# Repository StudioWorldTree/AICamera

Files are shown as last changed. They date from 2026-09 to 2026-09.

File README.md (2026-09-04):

# AICamera

Hardware home for the All Systems Go AI camera. Thor body, HEVC record path, Cooke /i lens metadata, hybrid CSI / PoE plant.

**Notebook:** [studioworldtree.github.io/AICamera](https://studioworldtree.github.io/AICamera/)

Product ground (pipeline, modes, models, vision) lives in `web3d-space`. This repo is the camera body: carriers, sensors, interconnect, enclosures, datasheets.

## Site

SvelteKit static + [mdsvex](https://mdsvex.pngwn.io). Markdown in `docs/`, `openspec/`, and `AGENTS.md` is compiled into `/docs/…`.

```sh
npm install
npm run dev
npm run build   # BASE_PATH=/AICamera in CI
```

### CMS

The notebook is still SvelteKit static + mdsvex. Editors use [Sveltia CMS](https://github.com/sveltia/sveltia-cms) at `/admin/` in local `npm run dev`, and at https://studioworldtree.github.io/AICamera/admin/ on Pages. Sign in with a GitHub personal access token that can write this repo (classic `repo`, or fine-grained `contents:write`). Token auth only; no OAuth worker in this pass. Commits go to `main` and Pages rebuilds. Do not put locked decisions, openspec packets, or CAD/GLB in the CMS.

## Kit (locked)

- Lab brick: Jetson AGX Thor Developer Kit = T5000 module
- Production ceiling: T4000 SOM unless satellite count forces T5000
- Bring-up: 1 body + 2 satellites at 4K30
- Record: HEVC. Lens: Cooke /i JSONL sidecar

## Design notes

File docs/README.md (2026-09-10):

---
title: "Hardware docs"
kicker: "Index"
group: "meta"
summary: "This repo is the camera body. Product ground (vision, pipeline, modes, models) lives in web3d-space. Do not fork it."
---

# AICamera hardware docs

This repo is the **camera body**: Thor carrier, sensors, interconnect, power, enclosures, datasheets.

Product ground (vision, pipeline 0–19, modes, models, scene loop) lives in

`~/work/Family/web3d-space/docs/all-systems-go/`

The SvelteKit app in that repo is the spatial viewer, not the EVF.

| Here | There (`web3d-space/docs/all-systems-go/`) |
|---|---|
| [STREAM-BUDGET.md](STREAM-BUDGET.md) | HARDWARE.md, BRAINSTORM.md |
| [MODEL-MAP.md](MODEL-MAP.md) | MODELS.md, PIPELINE.md, MODES.md |
| [INTERCONNECT.md](INTERCONNECT.md) | — |
| [CARRIER.md](CARRIER.md) | HARDWARE.md |
| [SENSORS.md](SENSORS.md) | — |
| [LENS.md](LENS.md) | MODES.md (lens sidecar) |
| [POWER.md](POWER.md) | — |
| [ENCLOSURE.md](ENCLOSURE.md) | — |
| [cad/](cad/) | STLs for Anycubic |
| [SHOPPING.md](SHOPPING.md) | Camera + T4000 carrier buy brief |
| [CAMERAS.md](CAMERAS.md) | CSI vs GMSL vs PoE H.265; turret vs module; lidar; Thor-in-body hold |
| [references/THERMAL.md](references/THERMAL.md) | TDG-12271-001 v1.3: TTP 75 °C, θpa, radiators not lots of fans |
| [references/T4000.md](references/T4000.md) | — (Arrow DS-11945-001 v1.4) |
| [3090-SIM.md](3090-SIM.md) | fractal1 RTX 3090 → T4000 translation; next RunPod SKU |

Do not fork VISION / PIPELINE / MODES / MODELS. Cite them. Hardware notes and CAD land here.

## Kit (steered 2026-09-01, AUTO)

- **Lab brick:** Jetson AGX Thor Developer Kit = T5000 module. QSFP28 + 5GbE + USB-C. Envelope 243.19 × 112.40 × 56.88 mm.
- **Production ceiling:** T4000 SOM (64 GB, 1× NVENC, default **70 W**, throttle at **90 W**, 87 × 100 × 15.29 mm) if the stream budget still fits; else T5000 SOM + carrier. See [references/T4000.md](references/T4000.md).
- **Fabric:** hybrid — body camera on CSI/GMSL mounted to the Thor box; satellites on PoE Ethernet (RV1126B).
- **Carrier:** Connect Tech **Rogue-T5** (AGX302) preferred. Thermal: metal radiator body; 70 W fanless not honest. See [references/THERMAL.md](references/THERMAL.md).
- **Bring-up count:** 1 body + 2 satellites at 4K30. 4-sat and 6-sat stay in the budget tables.
- **Coprocessor / vault:** RTX PRO 6000 and NAS, off-body. Already decided in web3d-space.

## Print

Anycubic resin printer on site. First enclosure is a fit-check of the AGX kit + body-cam mount, not a production housing. Blender MCP when connected.

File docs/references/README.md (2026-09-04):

---
title: "References"
kicker: "Sources"
group: "reference"
summary: "Where the Arrow datasheet lives, and how it was ingested (pdf2md, text-based, 59 pages)."
---

# References

Vendor PDFs. Extracted facts go in sibling `.md` files. Do not treat a PDF as unread if `pdf2md` has not been run.

| File | What | Date | Extract |
|---|---|---|---|
| [jetson_thor_series_modules_datasheet_ds-11945-001v1.4.pdf](jetson_thor_series_modules_datasheet_ds-11945-001v1.4.pdf) | NVIDIA Jetson Thor Series Modules (T5000 + T4000). Arrow download. DS-11945-001 **v1.4** Feb 2026. T4000 added in v1.3 (2025-09-29). | fetched 2026-09-01 | [T4000.md](T4000.md) |
| [jetson_thor_thermal_dg_tdg-12271-001v1.3.pdf](jetson_thor_thermal_dg_tdg-12271-001v1.3.pdf) | Jetson Thor Series Modules Thermal Design Guide. NVIDIA Developer. TDG-12271-001 **v1.3** May 18 2026. T4000 added v1.1. | fetched 2026-09-02 | [THERMAL.md](THERMAL.md) |

Still wanted (not in tree):

- Jetson Thor Series Modules **Design Guide** DG-12084-001 (carrier pins, MGBE PHY, CSI)
- **AGX Thor Developer Kit** datasheet (the 243 × 112 × 57 mm brick)
- NVIDIA Jetson Thor Series Module **3D CAD STEP** (P3834) — needed before metal body fit

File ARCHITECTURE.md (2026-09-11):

# Architecture

`cartridge-runtime` is the catalog and packer contract. The catalog JSON
is `sim/3090/catalog.json`. Packing (`add-cartridge-pack`) is later.

## Parakeet ASR process (add-parakeet-api)

GitHub Pages is adapter-static SSG. The ASR API is a **standalone Bun
process** on fractal1 (`asr/server`), sibling to `aicam-bay-feed`
(`:8745`), not mounted in SvelteKit. Bind is the Tailscale IPv4 only on
**`:8750`**. UPnP is on; never `0.0.0.0`.

```
caller --HTTP--> Bun Hono :8750  --stdin/IPC-->  Python onnx-asr sidecar
                 OpenAPI here                    INT8 TDT v3, CPU EP
```

Hono owns HTTP, Zod, and the generated OpenAPI 3.1 document. The sidecar
owns the model (`CUDA_VISIBLE_DEVICES=` empty, `CPUExecutionProvider`,
≤4 intra-op threads). The sidecar has no network listener; Bun is the
sole tailnet socket.

Discovery copies daBOM: `GET /.well-known/openapi.json` (canonical,
`servers: [{ url: '/api/v1' }]`) is the same bytes as
`GET /api/v1/openapi.json`; `GET /.well-known/api-catalog` is RFC 9727.
Agents read well-known. Clip is `POST /api/v1/transcribe`; stream is
windowed TDT emitting NDJSON `{text, t0, t1, final}`.

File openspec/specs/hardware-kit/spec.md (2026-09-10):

# hardware-kit

Living spec for the All Systems Go camera body. In-flight deltas:
`openspec/changes/*/specs/hardware-kit/`.

## Purpose

CAD and buys use envelopes and URLs from `docs/references/`, not folklore.
The kit crib (SKUs, BOM lines, quotes) is sister repo `daBOM`. Preferred
production kit is SKU `kit-prod` (Cart T). Lab brick is `kit-lab`. Hybrid
1+2 plant is `kit-hybrid-plant`. Explode with
`GET /api/v1/items/{sku}/bom?explode=true`. This markdown is capability
SHALLs, not the parts list.

## Requirements

### Requirement: Kit crib
The preferred production kit SHALL be the daBOM item `kit-prod` (Cart T —
T4000 + Rogue-T5). Lab bring-up SHALL be `kit-lab`. The 1 body + 2 sat
plant SHALL be `kit-hybrid-plant`. SKUs, BOM lines, and quotes SHALL be
read from daBOM, not copied into this spec.

#### Scenario: explode production kit
- GIVEN daBOM is running
- WHEN `GET /api/v1/items/kit-prod/bom?explode=true`
- THEN the tree includes the T4000 SOM, Rogue-T5, and satellite encode
  mules, not a handwritten parts list in this file

### Requirement: Datasheet manifest
Every steered SKU SHALL have a PDF or URL, fetch date, and mechanical
envelope listed under `docs/references/`.

#### Scenario: Thor SOM
- GIVEN DS-11945-001 v1.4 in `docs/references/`
- WHEN CAD or power work starts
- THEN envelopes come from [T4000.md](../../../docs/references/T4000.md), not memory

### Requirement: Cooke /i–class lens sidecar
Each camera, body and satellite, SHALL produce frame-accurate lens
metadata in Cooke /i (or ARRI LDS, ZEISS XD, or EF electronic mapped
into the same fields). Thor SHALL write it as a JSONL sidecar 1:1 with
that camera’s HEVC timecode. RAW lens maps (/i3 distortion, shading)
SHALL be files on the NAS keyed by lens identity, not per-frame blobs.

#### Scenario: body and two sats
- GIVEN three cameras recording
- WHEN a take is written to the NAS
- THEN each HEVC file has a sibling JSONL with at least make, serial,
  true focal length, T-stop, and focus distance locked to timecode

### Requirement: First-article enclosure
The first printable enclosure SHALL fit the AGX Thor Developer Kit
envelope and provide a body-camera mount plus TTP ventilation.

#### Scenario: Anycubic fit-check
- GIVEN the AGX kit dimensions 243.19 × 112.40 × 56.88 mm
- WHEN an STL is printed in resin
- THEN the kit seats, the body cam has a mount, and vents do not cover the TTP

### Requirement: Split power tree
Thor module power and satellite PoE SHALL be separate supplies. PoE SHALL
NOT backfeed the AGX kit or SOM.

#### Scenario: sag
- GIVEN thermal or power headroom is gone
- WHEN the kit must shed load
- THEN AI (MIG slice 1) is dropped and record (slice 0) continues

### Requirement: T4000 thermal ceiling
A T4000 body SHALL be designed for 70 W default and 90 W TMP, TTP ≤ 75 °C.

#### Scenario: enclosure
- GIVEN a resin lid over the SOM or AGX kit
- WHEN the GPU is at default power
- THEN the TTP is vented or heat-sunk; resin is not the thermal path

### Requirement: Body-mounted camera
One camera SHALL be mounted to the Thor enclosure and ingested over
CSI-2 or GMSL into Thor NVENC. It SHALL be 4K30 class. HSB or USB on
the AGX kit is a bring-up fallback only and SHALL NOT be the production
body path.

#### Scenario: body record
- GIVEN the body camera is mounted and powered on the production enclosure
- WHEN capture starts
- THEN Thor encodes H.265 from that CSI/GMSL sensor without a PoE hop
  and without using HSB/USB as the ingest

### Requirement: PoE satellites
Bring-up SHALL include two satellite cameras on PoE that emit H.265 at
4K30. The shipped satellite class SHALL support electronic iris and/or
focus, a Cooke /i–class metadata path (barrel port to Ethernet), and a
UART 1D ToF sensor whose range is written into the same JSONL sidecar
as picture. A sealed P-iris turret MAY be an encode mule for bring-up
and SHALL NOT be the shipped satellite class.

#### Scenario: satellite record
- GIVEN two PoE satellites of the shipped class and a PoE switch
- WHEN capture starts
- THEN each satellite delivers camera-side H.265 that Thor remuxes to
  the NAS, plus Cooke-class lens metadata and 1D ToF in the sidecar,
  without a RAW Ethernet payload

### Requirement: Lab brick
Bring-up SHALL use the NVIDIA Jetson AGX Thor Developer Kit (T5000 module).

#### Scenario: first power-on
- GIVEN no custom carrier yet
- WHEN the lab kit is used
- THEN I/O is the kit’s 5GbE, QSFP28 (independent MGBE lanes), USB-C, and HSB/USB cameras

### Requirement: Production ceiling
Production body design SHALL fit the T4000 SOM: 87 × 100 × 15.29 mm,
699-pin B2B, default 70 W, throttle at 90 W TMP, 1× NVENC, 3× 25GbE,
no CAN. The carrier SHALL supply SYS_VIN_HV 7–20 V and SYS_VIN_MV 5 V.
It SHALL NOT require SYS_VIN_SV (a T5000-only rail). T4000 is the default
production module. T5000 is permitted only when the required satellite
encode load cannot remain camera-side or otherwise exceeds the validated
T4000 hybrid budget.

#### Scenario: drop to T4000
- GIVEN hybrid HEVC satellites
- WHEN the body is a T4000 SOM
- THEN Thor encodes the body camera only and satellites remain camera-side H.265

#### Scenario: rails
- GIVEN a production carrier for T4000
- WHEN the SOM is seated
- THEN HV 7–20 V and MV 5 V are present and SYS_VIN_SV is absent at the module

#### Scenario: T5000 escape
- GIVEN satellite count or encode demand that will not stay camera-side
  within the T4000 hybrid budget (1× NVENC, HQ 2× 4Kp30)
- WHEN the body module is chosen
- THEN T5000 may be used; otherwise the body stays T4000

### Requirement: Hybrid camera fabric
The camera body SHALL ingest the body camera over CSI-2 or GMSL on the
Thor module, and SHALL ingest satellite cameras over Power-over-Ethernet.
USB-C SHALL NOT be the satellite trunk.

#### Scenario: bring-up plant
- GIVEN one body camera and two satellites
- WHEN the kit is powered
- THEN the body path is native CSI/GMSL into Thor and each satellite is a PoE endpoint

### Requirement: HEVC record path
The kit SHALL record 4K picture as H.265. RAW SHALL NOT be required on
the satellite or truck uplink. CSI RAW is permitted only as the body
sensor hop into Thor NVENC. Satellite H.265 SHALL be written to the NAS
by Thor (remux, no re-encode) alongside the body master.

#### Scenario: bring-up bit rate
- GIVEN 1 body + 2 satellites at 4K30 HEVC
- WHEN streams are recorded
- THEN aggregate payload is on the order of 0.24 Gbps and fits in 5 GbE

### Requirement: Satellite-side encode for T4000 bring-up
On the T4000 production ceiling (1× NVENC, HQ 2× 4Kp30), each satellite
SHALL encode its own H.265. Thor NVENC SHALL own the body master only.
The kit SHALL NOT require Thor to HQ-encode the 1 body + 2 satellite
bring-up trio.

#### Scenario: T4000 HQ ceiling
- GIVEN T4000 HQ NVENC is 2× 4Kp30
- WHEN 1 body + 2 satellites record 4K30
- THEN the body is Thor NVENC and each satellite ships camera-side H.265

### Requirement: PoE power vs data boundary
PoE SHALL power satellites. The satellite Ethernet PHY SHALL carry H.265.
Thor SHALL NOT supply PoE. An external PoE switch is a kit item. PoE class
and switch uplink capacity SHALL be evaluated as separate criteria; PoE
does not name link bitrate.

#### Scenario: switch is in the kit
- GIVEN Thor has no PoE
- WHEN two satellites are on set
- THEN each sat is a PoE endpoint on an external switch, and that switch’s
  data uplink is sized for the HEVC payload plus overhead, not by PoE class

### Requirement: Independent MGBE lanes
QSFP/MGBE lanes on Thor SHALL be treated as independent controllers.
The kit SHALL NOT present QSFP28 as one aggregated 100GbE video trunk.

#### Scenario: QSFP is not 100G
- GIVEN QSFP28 is three (T4000) or four (T5000 / AGX kit) independent MGBE controllers (DS-11945-001 4.10.1)
- WHEN the truck uplink is planned
- THEN each lane is budgeted on its own; the plant is not a 100G pipe

### Requirement: Clock and sidecar alignment
Body hardware timing, satellite PTP, picture timecode, and Cooke /i–class
JSONL SHALL be reconcilable per frame. The exact product clock master MAY
remain unspecified.

#### Scenario: sidecar locks to picture
- GIVEN a take written to the NAS
- WHEN a HEVC file and its JSONL sidecar are opened
- THEN timecode on the sidecar matches picture; satellite PTP and body
  hardware clocks are named well enough to reconcile them

### Requirement: Record-first under AI drop
HEVC recording, the NVMe ring, satellite remux to storage, and metadata
sidecars SHALL continue when AI decode or overlay is dropped. Mode switch
drops AI, never record. Remux is record, not AI.

#### Scenario: thermal sag
- GIVEN 1 body + 2 satellites recording
- WHEN slice-1 AI is killed or thermal sag drops overlay/AD
- THEN body HEVC, sat remux to the NAS, and JSONL sidecars keep writing

### Requirement: Four compute envelopes
The kit SHALL name four compute envelopes: Thor T4000 (production body),
fractal1 RTX 3090 (local FP16 pipe), RunPod RTX PRO 6000 Blackwell Server
96 GB (30 fps perception lab), and the truck 6000 (quality). The AGX Thor
Developer Kit (T5000 module) SHALL share envelope id `t4000` until
measured apart: bandwidth-bound reads ~1× T4000, TPC-bound ×0.6, NVENC
count 2 not 1. The 3090 SHALL NOT be treated as a T4000 TOPS proxy.
Derates SHALL live in `docs/3090-SIM.md`. Hardware envelope id (derate
and log attribution) and pack id (SMALL or LARGE weights) SHALL be
separate fields. Pack and residency default by envelope and SHALL be
overridable. RunPod 6000 and truck 6000 share the `6000` quality-class
column until measured apart.

#### Scenario: cartridge costs
- GIVEN the cartridge catalog
- WHEN costs are recorded per envelope id
- THEN the ids `t4000`, `3090`, and `6000` match this four-box list
  (RunPod 6000 and truck 6000 share the `6000` quality-class column
  until measured apart; the AGX kit logs as `t4000` with the partial
  derate above)

### Requirement: Resident 30 fps design target
The live perception pipeline SHALL be designed as named slots kept
resident at 30 fps on Thor T4000 and on an RTX PRO 6000. fractal1’s
3090 SHALL emulate that pipeline by loading one slot at a time and
unloading it, and SHALL NOT be a 30 fps host. The same software SHALL
select residency (`resident` or `swap`) and pack (`SMALL` or `LARGE`)
as independent fields that default by envelope id and MAY be overridden.
A PRO 6000 LARGE-pack stream SHALL NOT be logged as a T4000 FACT; no
derate from 6000 fps to T4000 exists. T4000 30 fps SHALL remain SPEC
until measured on Thor silicon. Swap-mode logs SHALL split load/unload
time from per-frame time before `docs/3090-SIM.md` derates apply.

#### Scenario: rent or local body
- GIVEN the live mix is running
- WHEN the envelope is a rented PRO 6000 96 GB
- THEN every live slot stays resident, pack is LARGE, and the stream is
  a lab result with no derate to T4000
- WHEN the envelope is a local T4000
- THEN every live slot stays resident, pack is SMALL, and 30 fps is SPEC
- WHEN the envelope is fractal1 3090
- THEN slots swap, pack is SMALL, and the log splits load/unload from
  per-frame time then applies `docs/3090-SIM.md` derates

### Requirement: Envelope-sized packs
T4000 SHALL pack SMALL live weights (VDA-S / oVDA, YOLOE, SAM2-tiny or
EdgeTAM, RVM-MN3 on talent, Maxine AR). The 30 fps lab 6000 SHALL pack
LARGE live weights (VDA-L or DA3METRIC-L, SAM 3.1, SAM2Matting). The
3090 SHALL load SMALL weights only. SAM 3.1 + VDA-L SHALL NOT be packed
on T4000.

#### Scenario: MODELS quant rows
- GIVEN MODELS.md
- WHEN a live perception job is listed
- THEN it names SMALL and LARGE packs and which envelope runs each

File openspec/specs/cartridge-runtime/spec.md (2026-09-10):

# cartridge-runtime

Living spec for the cartridge catalog and packer contract. In-flight
deltas: `openspec/changes/*/specs/cartridge-runtime/`.

## Purpose

The packer and `/bay` read one catalog of cartridges: costs, shelves,
exclusive tags, and named-mode presets. Catalog JSON lives at
`sim/3090/catalog.json`. The packer algorithm is a later change.

## Requirements

### Requirement: Cartridge catalog
The kit SHALL expose a catalog of cartridges. Each cartridge SHALL have
an id, a kind (`model` or `plugin`), a `job` string pointing at the
MODELS.md row it fills, a shelf (`always-on`, `slottable`, or
`never-on-thor`), zero or more exclusive tags, and a cost record per
envelope id (`3090`, `t4000`, `6000`) with watts, NVENC sessions, and
either a 3090-shaped split (`vram_gb` + `host_ram_gb`) or a unified
pool (`unified_gb` on `t4000`). The packer SHALL sum `vram_gb` +
`host_ram_gb` against one ceiling on unified envelopes. Shelf
`never-on-thor` SHALL override any measured cost (policy, e.g. H3).
A null cost means unmeasured, not free.

#### Scenario: seed catalog
- GIVEN the catalog file for this repo
- WHEN a packer or `/bay` reads it
- THEN every always-on, slottable, and never-on-thor cartridge used by
  named modes is present with kind, shelf, and job set

### Requirement: Always-on reserved
Encode (NVENC HEVC) and pose (cuVSLAM) SHALL be always-on cartridges.
A pack SHALL NOT drop them. Thermal or power sag SHALL drop slottable
AI cartridges, never record.

#### Scenario: sag
- GIVEN a seated loadout that includes slottable AI
- WHEN thermal or power sag is signalled
- THEN encode and cuVSLAM remain resident

### Requirement: Null costs
On the target envelope: an always-on cartridge with a null cost SHALL
be `absent` (logged, not seated; the pack remains legal). A slottable
cartridge with a null cost SHALL NOT seat.

#### Scenario: cuVSLAM on fractal1
- GIVEN cuvslam is always-on and its `3090` cost is null
- WHEN a packer runs for envelope `3090`
- THEN cuvslam is absent and logged; slottable carts still pack

#### Scenario: slottable unmeasured
- GIVEN a slottable cart with null `3090` cost
- WHEN a packer runs for envelope `3090`
- THEN that cart does not seat

### Requirement: Exclusive tags
Cartridges that share an exclusive tag SHALL NOT be co-resident. Tags
this pass are `klein-27b` and `sam2-maxine-4k`. `sam2-maxine-4k` SHALL
apply only to 4K-class cart ids. EVF / 720p variants SHALL be untagged
so the talent-tracking preset (SAM2 + Maxine) seats. Other combinations
are legal if they fit the envelope.

#### Scenario: klein vs 27B
- GIVEN klein-4b and qwen-27b both requested
- WHEN the packer runs
- THEN the pack refuses; it names which cartridge to unslot

#### Scenario: talent-tracking at EVF
- GIVEN the talent-tracking preset with untagged SAM2-tiny and Maxine
- WHEN the packer runs
- THEN both seat; a 4K SAM2 cart and a 4K Maxine cart that share
  `sam2-maxine-4k` SHALL NOT

### Requirement: Swap envelope pack
On envelope `3090`, residency is swap (hardware-kit Resident 30 fps
design target): one slottable
slot loaded at a time beside always-on. A pack on a swap envelope SHALL
compare **Σ(always-on) + max(slottable)** against the envelope ceiling,
not the max over the whole set and not the sum of all peaks.
Sum-of-peaks is the rule on resident envelopes (`t4000`, `6000`).

#### Scenario: 3090 swap set
- GIVEN klein-4b, sam2-tiny, and clip are in the desired set
- WHEN the packer runs for envelope `3090`
- THEN the pack seats if always-on plus the largest slottable peak fits
  24 GB / 16 GB host; it SHALL NOT refuse because the sum of slottable
  peaks exceeds the brick

### Requirement: Named modes are presets
Named camera modes SHALL be arrays of cartridge ids in the catalog,
not a second exclusive runtime. The operator MAY unslot or slot from
a preset. Job names SHALL come from the product MODELS.md / MODES.md
list; this catalog SHALL NOT fork that prose.

#### Scenario: snap preset
- GIVEN the Creative snap preset
- WHEN it is applied
- THEN klein-4b is in the desired set and qwen-27b is not

### Requirement: Envelope id
The pack target SHALL be an envelope id. On fractal1 the live brick
SHALL be `3090`. Envelope `t4000` SHALL be available as a second scale
and SHALL NOT be reported as seated on the 3090.

#### Scenario: live brick
- GIVEN fractal1
- WHEN a cart is seated
- THEN the packer uses envelope `3090`; a T4000-only fit is a gauge,
  not a seated cart

### Requirement: Latency vs pack
Each cartridge SHALL record `latency` (`LIVE` / `NEAR` / `MIN` / `NIGHT`)
from MODELS.md. This packer SHALL be memory, host/unified RAM, and
NVENC only. Watts SHALL be recorded per cost and per envelope; power
enforcement is sag (`hardware-kit`), not seat/bounce. 30 fps residency
is hardware-kit Resident 30 fps design target (`pack` SMALL/LARGE and
`resident`/`swap`); it is a gauge, not a seat/bounce on this catalog.

#### Scenario: 9B + SAM2
- GIVEN qwen-9b (NEAR) and sam2-tiny (LIVE) both fit memory on `t4000`
- WHEN this packer runs
- THEN both seat; LIVE-slot count is not a refusal here

### Requirement: Envelope ceilings
The catalog SHALL list ceilings per envelope: on `3090`, VRAM GB, host
RAM GB, NVENC sessions; on `t4000` and `6000`, unified GB, NVENC
sessions. Watts may be recorded on the envelope but SHALL NOT be a pack
axis. This change owns those ceilings. hardware-kit Resident 30 fps
design target owns which box is which and swap vs resident.

#### Scenario: refuse over ceiling
- GIVEN envelope `3090` ceilings 24 GB VRAM / 16 GB host / 1 NVENC
- WHEN a single cart's 3090 peak exceeds 24 GB VRAM
- THEN it does not seat, even on a swap envelope

### Requirement: Cost provenance
Each cost record SHALL carry `src` (3090-SIM or MODELS.md anchor plus
date) or `fact: false`. Disk weight size SHALL NOT be recorded as a
VRAM peak.

#### Scenario: klein
- GIVEN klein-4b 3090 cost
- WHEN the catalog is read
- THEN `fact` is false or `src` does not claim 16 GB weights as VRAM peak

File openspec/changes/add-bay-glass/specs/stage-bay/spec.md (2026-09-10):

## ADDED Requirements

### Requirement: Bay glass reads as an EVF
`/bay` SHALL present VRAM, power, RAM, zram vs disk swap, and the model
mag rack in a dark EVF chrome (tungsten, tally, waveform). It SHALL NOT
use the docs paper-grid as the primary surface.

#### Scenario: idle brick plate
- GIVEN last plate or live idle snapshot
- WHEN `/bay` renders
- THEN VRAM readout, waveform fill, and mag rack are visible on a dark field

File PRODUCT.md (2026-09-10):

# Product

## Register

product

## Users

Duke on the brick EVF: watching fractal1’s 3090 while models swap. Not a
public marketing page. `/bay` is a filmmaker tally — tungsten, digits,
what is in the gate.

## Product Purpose

Show what the GPU is doing: VRAM, draw, which cartridges are on the cart
versus in the gate. Success is an honest loadout, not a dashboard of
vanity metrics.

## Brand Personality

Tungsten, tally, waveform. Space Age lock-in, Tactic Extra Extended
Black HUD digits. Vaporwave lives *behind* the VRAM graph as a reaction
layer, not as the chrome of the page.

## Anti-references

Neon-grid as the whole UI. Generic SaaS metric cards. Copying the Tron
Legacy score (copyright). Mag rack that labels every slot ON CART
whether or not anything is resident.

## Design Principles

- The graph is the set; the grid is the sky behind it.
- Mag rack matches the catalog and the process list.
- Spin-up is felt: speed, filter, count — not a toast.
- Reduced motion still reads the numbers.

## Accessibility & Inclusion

WCAG AA on type and tally. `prefers-reduced-motion` freezes the grid
and does not start audio. Sound is opt-in (click to arm).

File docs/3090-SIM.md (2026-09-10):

---
title: "3090 → T4000 translation"
kicker: "Sim"
group: "hardware"
summary: "fractal1 RTX 3090 is the slow swap emulator of a resident-30fps pipeline. CUDA cores are the wrong axis. Derate bandwidth-bound fps ×0.30, CUDA-core filters ×0.13. 30 fps lab SKU: RunPod PRO 6000 96 GB — no derate to T4000."
---

# 3090 as a T4000 sim

Local brick: **fractal1**, Arch, `ssh fractal1` (user `dorje`). RTX 3090 24 GB, **16 GB host RAM**. Not the quality box. Not a T4000. Not a 30 fps host.

The live mix is designed **everything resident at 30 fps**. This box **emulates** that pipeline by loading **one SMALL slot at a time** and unloading it. Slow on purpose. Same software as a local T4000 or a rented RTX PRO 6000 Blackwell Server 96 GB, which keep slots resident.

A PRO 6000 stream is a LARGE-pack **lab result**. There is **no derate** from 6000 fps to T4000 (1792 vs 273 GB/s). T4000 30 fps stays SPEC until measured on Thor silicon. No box in the four-envelope list validates resident-set fps at 273 GB/s except Thor itself.

Swap-mode logs SHALL split **load/unload time** from **per-frame time** before ×0.13 / ×0.30 apply. Do not derate a number that still includes weight load (the klein row below currently conflates; next measurement splits it).

Cloud T4000-shaped runs stay on RunPod (Blackwell, FP8/FP4). This box is HEVC plumbing + FP16 nets + the translation table below.

T4000 FACT is DS-11945-001 v1.4 @ **70 W**. See [references/T4000.md](references/T4000.md). Product sim: `web3d-space/docs/all-systems-go/GPU-SIM.md`.

## Do not divide by CUDA cores

| | RTX 3090 | T4000 @ 70 W | 3090 / T4000 |
|---|---|---|---|
| Arch | Ampere sm_86, 3rd-gen tensor | Blackwell sm_110, 5th-gen + TMEM | different |
| CUDA cores | 10496 | **1536** (2 GPC / 6 TPC) | 6.8× — **wrong axis** |
| FP32 CUDA | 35.6 TFLOPS | **4.7 TFLOPS** | 7.6× |
| FP16 tensor dense / sparse | ~142 / ~285 TFLOPS | ~150 / ~300 TFLOPS | **~1×** |
| INT8 (= FP8 on Thor) dense / sparse | ~285 / ~570 TOPS | **300 / 600 TOPS** | **~1×** |
| FP8 sparse | no hardware | **600 TFLOPS** | T4000 only |
| FP4 sparse | no hardware | **1200 TFLOPS** | T4000 only |
| Bandwidth | **936 GB/s** GDDR6X | **273 GB/s** LPDDR5X | 3090 **3.4×** |
| Capacity | 24 GB discrete + 16 GB host | **64 GB unified** | T4000 wins envelope |
| NVENC | 1× Ampere | 1× Blackwell, HQ **2× 4Kp30** | same count; 3090 overstates headroom |
| PVA / OFA | none | PVA 3.0 + optical flow | not emulatable |
| Power | 350 W | 70 W / 90 W throttle | do not `nvidia-smi -pl 70` and call it T4000 |

Datasheet: *FP8 TFLOPs is equivalent to INT8 TOPs.*

## Translation table (read 3090 numbers as T4000)

| If you measured on 3090… | Multiply by | Why |
|---|---|---|
| CUDA-core filter fps (color, warp, undistort, RVM conv) | **× 0.13** | FP32 4.7 / 35.6 |
| SAM2 / ViT / LLM **prefill** at FP16 | **× ~0.30** | bandwidth 273 / 936; tensor ~1× |
| LLM **decode** tok/s | **× ~0.30** | decode is GB/s |
| FP8 / NVFP4 TRT | **cannot** | Thor-only. 3090 understates production Thor |
| Fits in 24 GB | **fits T4000 64 GB** | 3090 is the pessimistic envelope |
| OOM on 24 GB | **unknown on T4000** | 9B + klein + SAM2 is a 64 GB yes, 24 GB maybe-not |
| 3× 4K NVENC | **fail T4000 HQ** | T4000 HQ is 2× 4Kp30 |

Do not derate by 6.8 (core count). Do not treat 16 GB host RAM as a T4000 limit — Thor unified 64 GB eats the “host” half.

Live stack we care about (NVENC + SAM2-tiny + DA-S + one of 9B / klein) is a **273 GB/s and 70 W** problem on Thor. 3090 makes the nets look cheap and the memory envelope look expensive. Trust the second, haircut the first.

## Ideal next hardware (RunPod)

No RunPod SKU is 6 TPC / 273 GB/s / 70 W. Pick by **which lie** you are correcting. This 3090 cannot do FP8/FP4; that is the cloud job.

| Job | Rent | Why | Not |
|---|---|---|---|
| **Quant / kernels** (FP8 SAM2, NVFP4 klein, TRT) | **RTX PRO 4000 Blackwell 24 GB** (~$0.57/hr) or keep **PRO 4500 32 GB** (`lduog58vatxh44`, $0.72/hr, EU-RO-1) | Same 5th-gen tensor as T4000. 4000 is the cheapest Blackwell. 4500 is already the `/gpu` worker. | Tesla T4, Ampere 3090/A6000, Ada L40S as a T4000 |
| **30 fps all-filters resident** (LARGE pack) | **RTX PRO 6000 Blackwell Server 96 GB** (~$2.09/hr) | The lab SKU. Same software as T4000. Capacity holds. TOPS will lie *high* — **no derate to T4000**. | 24/32 GB cards for the co-resident test |
| **Memory envelope** (9B + klein + SAM2 co-resident, the 64 GB question) | same PRO 6000 96 GB | Only common discrete that holds ≥64 GB. | — |
| Quality / DiT | truck PRO 6000 — already the quality box, not a T4000 sim | — | — |

**Next dedicated T4000-shaped cloud run:** PRO 4000 Blackwell if we only need FP8/FP4 kernels; PRO 6000 Blackwell if we are testing the resident LARGE pack. Do not terminate `negotiated-gpu-drafttrain-*`. Auto-off 30 min on `aicam-*` pods. Do not rent until someone says go.

Tesla **T4** is Turing 16 GB. Wrong generation, wrong memory, wrong encode. We are not renting one.

## Local harness

`sim/3090/` on this repo, synced to `dorje@fractal1:~/aicam/`. Stages unload between jobs (16 GB host).

```
ssh fractal1
cd ~/aicam && ./run.sh          # filters → SAM2 → CLIP regions → klein snap
```

Apply the table to any fps / tok/s we print. Fill [Measured](#measured) when a stage lands.

## Measured

fractal1, 2026-09-09. SAM2 bedroom.mp4, 48 frames @ 960×540. Harness `~/aicam/`.

| Stage | 3090 (FACT) | T4000 read (table) | Notes |
|---|---|---|---|
| CUDA-core look-dev (unsharp, grade, vignette, grain) | **266–281 fps**, ~700 MB, 44–59 W | **×0.13 → ~35 fps** | LIVE on T4000. Easy. |
| SAM2.1 Hiera-tiny AMG (float32) | **1.46–1.53 s/frame** (~0.67 fps), ~2.0–3.0 GB, ~390–407 W | **×0.30 → ~0.20 fps** | This is **AMG**, not live track. Tiny only returned 2 corner masks on this clip (lamp, floor). Live path is detector-keyframe + tiny tracker. |
| CLIP ViT-B/32 region embed | **4–7 ms** for 2 crops | bandwidth-bound, still cheap | Maps mask crop → prototype (`a lamp`, `a floor`). Cosine ~0.23–0.25 — weak because AMG missed the subjects. |
| FLUX.2 klein 4B 768², 4 steps, cpu_offload | **t2i 43 s** (load + warmup in that); **i2i 36 s** | FP16 ~1×; Thor FP8/NVFP4 may beat | Apache 4B. 16 GB host survived via offload. Unload SAM2 first. |
| Qwen3.5-9B | not this pass | decode ×0.30 | Host RAM. Next: after klein unload, or RunPod 96 GB envelope. |

## Bay glass

Live metrics are **`vite dev` only** (`import.meta.env.DEV` → `/bay-api` → MagicDNS `fractal1:8745`). GitHub Pages and any static HTTPS build show the last plate. A tailnet-served `vite preview` stays on plate.

Refresh the plate:

```
ssh fractal1 python3 ~/aicam/snapshot.py > src/lib/bay/last-plate.json
```

Derates ×0.13 / ×0.30 live in this file and `src/lib/bay/t4000.ts`. The feed does not emit them.

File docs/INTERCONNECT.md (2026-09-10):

---
title: "Interconnect"
kicker: "Plant"
group: "hardware"
summary: "Hybrid fabric: body CSI/GMSL into NVENC, sats PoE H.265, lens /i as a second stream. HEVC bring-up fits 5GbE."
---

# Interconnect

Activated with `aicam-interconnect`. Spec delta: `openspec/changes/add-camera-interconnect/`.

## Plant

```
[body cam] --CSI/GMSL--> Thor ISP --> NVENC H.265 --> NVMe ring --> 5/10/25GbE --> NAS
[body /i ] --PL pins or barrel--> UART/USB on Thor ----------------+--> JSONL sidecar
[sat 1]    --PoE H.265--> PoE switch --\                            |
[sat 1 /i] --/i port--> Lockit+ or ONVIF meta --> switch --\        |
[sat 2]    --PoE H.265--> PoE switch ---+--> Thor remux / NVDEC ----+--> NAS
                                         PoE switch is a kit item (Thor has no PoE)
```

Lens metadata is a second stream, 1:1 with picture, not inside the HEVC.
See [LENS.md](LENS.md).

## Decisions

| Fork | Call |
|---|---|
| Fabric | Hybrid: body on CSI/GMSL, satellites on PoE |
| Record | **H.265**. RAW is CSI-into-SoC only |
| Uplink | HEVC bring-up fits **5GbE**. 10/25GbE is NAS/headroom |
| QSFP28 | Independent MGBE lanes, not aggregated 100G |
| USB-C | Not the satellite trunk (short, shared, no PoE) |
| Encode split | Body = Thor NVENC. Sats = camera H.265, Thor remux to NAS (no re-encode). T4000 HQ is 2× 4Kp30 |
| Time | PTP on sats; GMSL/HW on body. SMPTE genlock unproven |
| GMSL2 count | Honest **4× 4K30 RAW** (8× 2-lane/1080p) on one JCB022. 20 is HSB. Sats scale on PoE H.265, not more FAKRA. |
| Sat SoC | **RV1126B** (RV1126 ok). Turret = encode mule; module = product (UART for /i + 1D ToF). |
| Lidar | 1D ToF on every sat sidecar. One Ethernet 3D lidar on the rig, not per camera. |
| Lens | Cooke /i class from **every** camera, sidecar JSONL |

## Why HEVC

DS-11945-001 v1.4: T4000 1× NVENC, HEVC HQ 2× 4Kp30 / 1× 4Kp60. Hardware
encode exists. One 4K30 HEVC is ~80 Mbps; three is ~0.24 Gbps. Gigabit
PoE + 5GbE is the plant. Uncompressed 4K30 10-bit 4:2:2 is ~5 Gbps and
is not the satellite budget.

## Still open

- Exact PoE switch SKU (at vs bt)
- PTP vs camera TC vs slate clock (product, not model)
- Hero uncompressed sat — exception, not v1

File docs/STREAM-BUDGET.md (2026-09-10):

---
title: "Stream budget"
kicker: "Numbers"
group: "hardware"
summary: "Working haul is ~100 Mbps per 4K30 HEVC. T4000 HQ encodes 2× 4Kp30, not three. QSFP28 is independent 25G lanes, not aggregated 100G."
---

# Stream budget — 4K in, 4K out

Feeds `aicam-interconnect`. Does not pick the fabric; it says which links survive which payload.

**Record path is HEVC, not RAW over the wire** (2026-09-01). Thor and/or the satellite cameras have hardware 4K H.265. CSI/GMSL RAW exists only as the body sensor → ISP → NVENC hop on the module. Do not budget 5–10 Gbps per satellite.

Bring-up row: **1 body + 2 satellites, 4K30**. 4-sat and 6-sat are tabled. Hybrid fabric (body CSI/GMSL, satellites PoE HEVC) is the working assumption.

## Payload per stream (payload only, no protocol overhead)

| Class | What | 4K30 | 4K60 | Notes |
|---|---|---|---|---|
| RAW12 Bayer | 3840×2160×12/8 × fps | **2.99 Gbps** | **5.97 Gbps** | Often shipped in 16-bit containers → same as 8-bit 4:2:2 |
| 8-bit 4:2:2 | 3840×2160×2 × fps | **3.98 Gbps** | **7.96 Gbps** | |
| 10-bit 4:2:2 | 3840×2160×2.5 × fps | **4.98 Gbps** | **9.95 Gbps** | Matches 12G-SDI ~11.88 Gbps with overhead |
| HEVC contribution | UHD Forum 2160p50/60 Main10 | — | **50–80 Mbps** | Cinema proxy often 100–200 Mbps |
| HEVC HQ on-set | working number | **40–80 Mbps** | **80–150 Mbps** | NVENC; not a distribution encode |

Working number for **what we haul:** **~100 Mbps per 4K30 HEVC** (NVENC HQ on-set). The RAW/4:2:2 rows stay as a ceiling for a hero uncompressed sat or for CSI into the SoC — not the satellite plant.

## Thor encode (FACT, DS-11945-001 v1.4 tables 2-4 / 2-5)

YUV420 8-bit, indicative. NVENC shares the GPU rail. Local copy: [references/jetson_thor_series_modules_datasheet_ds-11945-001v1.4.pdf](references/jetson_thor_series_modules_datasheet_ds-11945-001v1.4.pdf). T4000 extract: [references/T4000.md](references/T4000.md).

| SKU | NVENC | HEVC HQ 4Kp30 | HEVC HQ 4Kp60 | HEVC UHP 4Kp30 | HEVC UHP 4Kp60 |
|---|---|---|---|---|---|
| **T4000** 70 W | 1× | **2** | **1** | 6 | 3 |
| **T5000** 120 W | 2× | **4** | **2** | 12 | 6 |

AGX Thor Developer Kit = **T5000 module**. There is no T4000 kit.

**Implication:** T4000 HQ cannot Thor-encode 1 body + 2 sats at 4K30 (needs 3). That is an **NVENC count** problem, not a cable problem. Hybrid: Thor NVENC on the body cam; satellites encode H.265 on camera; Thor remuxes those streams to the NAS (no re-encode). T5000 HQ can encode the trio on-module if we want.

Six 4K60 on Thor is UHP, not a quality-master promise. HEVC decode for AD/overlay is the other budget: T4000 1× NVDEC, 4× 4Kp60 HEVC Main10 — do not decode six 4K60 for the VLM.

## Links (usable, not wire-rate)

| Link | Wire | Honest video | Length | Role on this kit |
|---|---|---|---|---|
| USB-C 3.1 (AGX kit) | 10 Gbps | ~8 Gbps shared, short | meters | Not the multi-4K trunk. Debug, disk, one webcam. |
| USB4 / TB4 | 40 Gbps | ~32 Gbps, shared, short | meters | Still a bad trunk for satellites. |
| 5GbE (AGX RJ45) | 5 Gbps | ~4.5 Gbps | 100 m | One HEVC bundle, or **one** uncompressed 4K30 if nothing else talks. |
| 10GbE | 10 Gbps | ~9 Gbps | 100 m copper / fiber | ~1 uncompressed 4K30 10-bit, or **dozens** of HEVC 4K. |
| 25GbE (T4000 **3×**, T5000 **4×**) | 25 Gbps each | ~23 Gbps each | fiber/DAC | 4 uncompressed 4K30 **per lane**. T4000 total **75 Gbps**, T5000 **100 Gbps**. |
| QSFP28 cage | 4×25 or 4×10 | **not aggregated 100G** | fiber | DS 4.10.1 note 2: lanes stay independent MGBE controllers. A 100G peer in 100G mode will not link. |
| GMSL2 | ~6 Gbps/link | one 4K30 RAW-class | coax, tens of m | Body cam / industrial sats. Needs a GMSL carrier; AGX kit is HSB/QSFP + USB, not 8× FAKRA. |
| HSB (Holoscan Sensor Bridge) | Ethernet sensor bridge | sensor-over-Ethernet into Thor | | NVIDIA’s Ethernet-sensor story. Worth a candidate next to GigE Vision. |
| PoE (af/at/bt) | power, not a bitrate | 15.4 / 30 / 60–90 W | 100 m | Satellites. Thor has **no** PoE — add a switch. Data rate is the PHY (1/2.5/5/10G), not the PoE class. |

## Kit rows

Payload = satellites + body. “Thor encode” is NVENC HQ 4K30 count.

| Kit | Uncompressed 10-bit 4:2:2 | HEVC ~80 Mbps | Thor-encode all? | Uplink that fits HEVC | Uplink that fits uncompressed |
|---|---|---|---|---|---|
| **1+2 4K30 (bring-up)** | ~15 Gbps | ~0.24 Gbps | T4000 HQ **no** (2 vs 3). T5000 HQ **yes**. Hybrid: yes on T4000. | **5GbE** is enough | **25GbE** (5GbE is not) |
| 1+4 4K30 | ~25 Gbps | ~0.40 Gbps | T4000 HQ no. T5000 HQ maybe at HP. Hybrid: yes. | 5GbE | 25GbE / 2×25 |
| 1+6 4K60 | ~70 Gbps | ~1.0 Gbps | T4000 no. T5000 UHP 6× 4Kp60, HQ only 2×. | 5GbE still yes for HEVC | **3× or 4× 25GbE** (not one 100G pipe) |

HEVC bring-up (1+2 at ~80 Mbps) is **~0.24 Gbps**. Gigabit PoE + the AGX **5GbE** jack covers it. 10/25GbE is headroom and NAS write, not a requirement to leave RAW behind. USB-C is still a bad satellite trunk (short, shared, no PoE); uncompressed columns are the exception path.

## Hybrid working plan

```
[body cam] --CSI/GMSL--> Thor NVENC --> NVMe ring --> 10/25GbE (or 3×25) --> NAS
[sat 1]    --PoE HEVC--> PoE switch --\ 
[sat 2]    --PoE HEVC--> PoE switch ----+--> Thor (decode for AI, remux to NAS)
```

- Record: HEVC. Body master from Thor NVENC; satellite masters are camera-side H.265 remuxed by Thor to the NAS.
- AI: Thor NVDEC sat proxies as needed (T4000 1× NVDEC).
- RAW stays on the module (CSI → ISP → NVENC). A hero uncompressed sat is a later exception, not v1.

## PoE power (order of magnitude)

| Class | Budget at PSE | Typical camera |
|---|---|---|
| 802.3af (PoE) | 15.4 W | small IP cam, no heater |
| 802.3at (PoE+) | 30 W | 4K box cam + iris motor |
| 802.3bt (PoE++) | 60–90 W | PTZ / heated / full cine servo |

2 satellites at PoE+ ≈ 60 W from the switch, plus Thor 40–70 W (T4000) or 40–130 W (AGX kit). Separate PSUs. Do not backfeed the AGX kit from PoE.

## Sources

- [DS-11945-001 v1.4](references/jetson_thor_series_modules_datasheet_ds-11945-001v1.4.pdf) (Arrow, Feb 2026): encode 2-4/2-5, MGBE 4.10.1, CSI 4.1, CoE 4.2, mechanical 6.4. Extract: [references/T4000.md](references/T4000.md)
- NVIDIA Jetson Thor product page: AGX kit = T5000
- 4K60 10-bit 4:2:2 ≈ 9.95 Gbps payload (12G-SDI class)
- Ultra HD Forum contribution HEVC 2160p50/60 ≈ 50–80 Mbps

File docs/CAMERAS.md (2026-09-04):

---
title: "Cameras"
kicker: "Pipes"
group: "hardware"
summary: "Thor speaks CSI-2, not GMSL. Body on the box is CSI. Sats are GMSL2, PoE H.265, or a cine HDMI/SDI body. Cable plant, not picture quality."
---

# CSI vs GMSL (and the rest of the camera pipes)

Thor never “speaks GMSL.” It speaks **MIPI CSI-2**. GMSL is a long-haul
truck that dumps CSI at the carrier.

```
sensor ──CSI-2──► [optional SerDes] ──cable──► [optional DeSer] ──CSI-2──► Thor NVCSI → ISP → NVENC
```

## CSI-2 (MIPI)

**What:** Phone/embedded camera bus. 2 or 4 data lanes + clock on a
flex (FFC) or tiny coax. D-PHY on Thor: **2.5 Gbit/s per pair, 40 Gbps
aggregate** (DS-11945). C-PHY exists; qualified slower than the brochure.

**Cable:** **~10–30 cm.** Past that, the eye closes. Not a set cable.

**Control:** I2C on the same flex (sensor registers, sometimes a VCM
for autofocus).

**Power:** Separate 1.8/2.8/3.3 V on the flex, or the carrier’s camera
header.

**On Thor:** Up to **6 cameras / 16 lanes**, 32 virtual channels. Body
cam bolted to the box is this.

**Cost:** Module $30–$400. No extra chips.

**Failure mode:** Flex rips, connectors walk out, EMI, length.

## GMSL (Gigabit Multimedia Serial Link)

Analog Devices (Maxim) SerDes. **GMSL2 ≈ 3 or 6 Gbit/s per coax.**
GMSL3 ≈ 12 Gbit/s. Automotive cameras, FAKRA connectors.

**What it really is:** CSI on the camera board → **serializer**
(e.g. MAX9295) → 50 Ω coax → **deserializer** on the carrier
(e.g. MAX9296) → CSI into Thor. I2C is tunneled. **Power over Coax
(PoC)** so one cable is video + control + 12 V.

**Cable:** **~8–15 m** (3 Gbps), sometimes 15–20 m. Locking FAKRA.
Vibration-proof vs CSI flex.

**On Thor:** Needs a deserializer card (CTI JCB022, Leopard adapter,
FORECR GMSL add-on). Jetson still sees CSI. Hardware frame-sync is
common (all sats share a trigger).

**Cost:** Camera $150–$800 + deserializer board $400–$1,500 + FAKRA
cables. BOM for 2 sats is real money vs CSI.

**Failure mode:** SerDes lock, I2C address clashes, PoC current,
driver not in the BSP. Bring-up is the hard part, not the pixels.

**GMSL3** is the newer, faster cousin. Same idea, fewer cameras in
catalog, CTI JCB009.

## How this maps to our kit

| Role | Pipe | Why |
|---|---|---|
| **Body on the Thor box** | **CSI-2** | 20 cm of flex. Lowest latency into ISP/NVENC/cuVSLAM. |
| **Sats across a set** | **GMSL2** *or* PoE H.265 *or* BMD HDMI/SDI | Need 5–15 m. CSI cannot. |
| **Cine A-cam (PYXIS)** | HDMI / 12G-SDI | Not CSI. See SHOPPING.md. |

CSI vs GMSL is **not** a picture-quality choice. Same Sony IMX can ship
as CSI *or* GMSL. You’re picking **cable plant**.

## Cousins (so the table is complete)

| Pipe | Distance | Into Thor as | Notes |
|---|---|---|---|
| CSI-2 | 10–30 cm | native | Body |
| GMSL2/3 | 8–15 m coax | DeSer → CSI | Sats, PoC, FAKRA |
| FPD-Link III | 10–15 m | DeSer → CSI | TI’s GMSL rival. Fewer Jetson boards |
| HSB / CoE | Ethernet | Holoscan Sensor Bridge | NVIDIA’s Ethernet-sensor story. AGX kit QSFP |
| HDMI | meters | bridge chip → CSI | Pocket cameras. 4K30 maybe |
| 3G-SDI | long | CTI JCB003 → CSI | **1080p only** |
| 12G-SDI | long | no cheap Jetson card | PYXIS 4K out; Thor can’t ingest 12G off-the-shelf |
| USB UVC | 3–5 m | USB | Easy, latency, not the take |
| GigE / PoE IP | 100 m | Ethernet, already compressed | Our original sat idea; no RAW into ISP |
| Cooke /i | milliamps serial | UART sidecar | Orthogonal. Almost no CSI/GMSL module has it |

## Lens metadata gap

Industrial CSI/GMSL cameras are **M12 or C-mount**, sometimes a tiny
VCM. They do **not** speak Cooke /i. C-mount can take cinema glass
mechanically; /i still needs the four PL pins or a barrel reader.

So:

- **CSI/GMSL body** = great pixels into NVENC, fake /i unless you add a
  reader.
- **PYXIS PL** = real /i, not CSI.
- Hybrid we already steered: cine body (BMD or PL CSI-box you build)
  + GMSL or PoE sats that may never be /i-class.

---

## Widened camera list (not Blackmagic)

Prices qty-1, 2026. Thor drivers are **not** guaranteed — Orin BSP is
the usual starting point.

### CSI-2 (body / close-in)

| Camera | Sensor | Res / shutter | Street | Notes |
|---|---|---|---|---|
| NVIDIA / Leopard **P3762** (IMX219-class kit cam) | small rolling | 1080p-ish | kit accessory | Dev-kit ribbon. Not 4K cine. |
| **Arducam xISP IMX678** | Sony Starvis2 1/1.8" | **4K15** rolling, UYVY (onboard ISP) | **$160** | Cheap 4K CSI for Orin NX. Confirm Thor DT. M12, no /i. |
| **Vision Components VC MIPI IMX585** | Starvis 1/1.2" **4K** | rolling, ~72 fps class | **~€245** 1ku flyer; proto higher | Proper module, source drivers. Optional GMSL2 adapter (~10 m). |
| **FRAMOS FSM:GO IMX900** | 3.2 MP **global** | PixelMate CSI | **$129** Mouser | Thor “preparing” (FRAMOS Aug 2026). Not 4K. Global shutter tracking. |
| **e-con e-CAM81_CUONX** | 4K HDR CSI | Orin NX/Nano | **~$99–200** kit | Orin, not Thor-listed. |
| Allied Vision **Alvium CSI-2** | many Sony/onsemi | C-mount | **$400–1,500** | Interchangeable glass. JetPack 6.2 drivers (Orin). Closest to “cine CSI.” |

### GMSL2 (sats)

| Camera | Sensor | Res | Street | Notes |
|---|---|---|---|---|
| **FRAMOS FSM:GO IMX900 GMSL3** | 3 MP global | not 4K | **$207** Mouser | Same module as CSI, FAKRA. |
| **e-con NileCAM81** | IMX678 4K | GMSL2, AGX Orin/Xavier | **~$99** module (+ kit) | 4K GMSL sat candidate. Thor BSP unknown. |
| **Leopard IMX390 GMSL2** | 2.1 MP automotive | 1080p HDR | **~$540–725** kit | ADAS, M12, 3 m FAKRA. Not 4K. |
| **Leopard AR0234 HAWK/OWL** | 2.3 MP global | stereo kits | **$149–3k** kits | Tracking/SLAM, not picture. |
| **Allied Vision Alvium GM2** | C-mount, many sensors | 1080p–4K depending | **$500–2,000** | **C-mount + GMSL2 + FAKRA.** Best “sat with real glass.” CTI Rogue documented (WDL). |
| **TechNexion VLS-GM2-*** | AR0144 etc. | 1 MP global, C-mount | **$163** | Cheap GMSL C-mount. |
| **D3 ISX031** sealed GMSL2 | 3 MP | **$624** | Automotive sealed. |

### Deserializer boards (required for GMSL)

| Board | Price | Host |
|---|---|---|
| CTI **JCB022** GMSL2 (8 ch, PoC) | quote | Gauntlet / Rogue-T5 |
| Leopard **LI-GMSL2-DESER-HOLOSCAN** | **$388** | Thor HSB / Holoscan, 1 cam |
| Leopard 8-ch AGX adapters | **$699** carriers | Orin-era; Thor TBD |
| D3 DesignCore 16-ch | **$799** | Orin kit, not Thor |
| FORECR GMSL2 add-on | quote | THRMAX |

---

## How I’d shop if we widen past Blackmagic

**Body (on the box):** CSI IMX585 or Alvium C-mount, 20 cm flex, Thor
NVENC. Add a PL /i reader later if you care. This is the *camera
Thor was designed for*.

**Sats:** Alvium GM2 or NileCAM81 GMSL2, 5–10 m FAKRA, PoC, hardware
sync. Not Cooke /i unless you bolt a reader on.

**Cine A-cam:** still PYXIS 6K PL if /i + BRAW matter. Parallel, not
instead of CSI.

You can mix: CSI body + two GMSL sats + PYXIS as a hero that records
its own card. Three different pipes, one NAS sidecar format.

## Don’t

- Assume a $160 Arducam “just works” on Thor JetPack 7. Device-tree
  work.
- Assume GMSL 4K @ 60. GMSL2 6 Gbps is tight for RAW12 4K60 (~6 Gbps
  payload). 4K30 RAW12 (~3 Gbps) is the honest sat.
- Buy GMSL without picking the **deserializer + BSP** in the same PO
  as the cameras.

---

## How many GMSL2 cameras can Thor actually host?

The brochure number is **8**. The honest 4K RAW number is **4**.
**20 is not GMSL** — that is HSB / Camera-over-Ethernet.

### The three ceilings (they are not the same)

| Ceiling | Number | What it actually means |
|---|---|---|
| Catalog deser board | **8** | CTI **JCB022**: 4× MAX9296A, 8× GMSL2 coax, 16 CSI lanes out, 75×57 mm, 45 g, PoC. Mates CTI Rogue-T5 / Gauntlet camera header. FORECR GMSL add-on is the same 8-ch story. |
| Thor NVCSI fabric | **16 lanes / 6 cameras / 32 VCs** | DS-11945 ch. 2.10 / 4.1. NVIDIA GMSL framework: **12 with ISP**, 16 VC with ISP / 24 without. T4000 has **one ISP**. |
| 4K30 RAW12 on GMSL2 | **4 at 4-lane, 8 at 2-lane** | Payload ~3 Gbps/cam. GMSL2 6 Gbps/link fits 4K30 RAW12; **4K60 RAW12 (~6 Gbps) does not**. A 4K module wants 4 CSI lanes after deser. 16 lanes ÷ 4 = **4 cameras**. 8 cameras on JCB022 is 2-lane each — 1080p-class or a squeezed 4K. |
| T4000 NVENC HQ | **2 × 4Kp30** | Even if 8 RAW streams arrive, Thor can HQ-encode two. The rest sit in DRAM or get UHP. |
| T4000 NVDEC | **9 × 4Kp30 HEVC** | Only matters if the sats already encoded. |

NVIDIA’s “up to 20 cameras” is **HSB / CoE** on Ethernet (FPGA bridge → MGBE), not FAKRA. Do not quote 20 as a GMSL2 count.

**Working number for this kit:** 1 CSI body on the box + **up to 4 GMSL2 4K30 RAW sats** on one JCB022 if we ever want RAW into ISP. 8 GMSL2 is a 1080p/2-lane plant. Past that, Ethernet.

Cable: **8–15 m** FAKRA + PoC. Not 100 m.

---

## GMSL2 RAW vs encode-on-camera then Ethernet

This is the real fork. Same pixels can leave the sensor as Bayer on coax
or as H.265 on Cat6. They are not interchangeable.

```
GMSL2:  sensor ──CSI──► MAX9295 ──6 Gbps coax 8–15 m──► MAX9296 ──CSI──► Thor ISP ──NVENC──► HEVC
PoE:    sensor ──CSI──► RV1126 ISP+HEVC ──~80 Mbps Cat6 100 m──► switch ──► Thor NVDEC (AI) / remux (record)
```

| | **GMSL2 (RAW into Thor)** | **Inline 4K H.265 + Ethernet** |
|---|---|---|
| What Thor sees | Bayer / YUV, native NVCSI | Already-compressed RTSP/ONVIF |
| Per-cam payload (4K30) | **~3 Gbps** RAW12 | **~40–80 Mbps** HEVC HQ |
| Honest cam count on T4000 | **4** 4K RAW (8 at 1080p) | **Dozens** on 5GbE; **~9** if Thor must NVDEC every stream for AI |
| Cable | 8–15 m 50 Ω coax, FAKRA, PoC | **100 m** Cat5e/6, PoE af/at |
| Power | PoC 12 V on the same coax | PoE switch (Thor has **no** PoE) |
| Sync | Hardware FSYNC through SerDes. This is why GMSL exists. | PTP / 802.1AS (Thor has it). Weaker than genlock. Fine for v1. |
| Latency | ~1 frame + SerDes lock | Encoder GOP + network. Cheap IPC is **50–200 ms**. Not a live EVF. |
| ISP / SLAM / NVENC on pixels | **Yes.** Thor ISP, cuVSLAM, NVENC HQ. | **No RAW.** Thor remuxes the take; NVDEC a proxy for AD/overlay. |
| Cooke /i | Almost never on the module. Add a barrel reader. | Same. UART sidecar over Ethernet is actually easier. |
| Bring-up | Device tree, I2C aliasing, SerDes lock, BSP. Weeks. | RTSP/ONVIF. Days. |
| BOM, 2 sats | Cams $150–2k + deser $400–1.5k + FAKRA | **$50–200 / cam** turret + a PoE switch |
| Failure | SerDes unlock, PoC current, DT | Network, GOP, ONVIF quirks |
| Catalog | Common in auto/industrial. Not cine. See list above. | Every IP camera on earth. |

**When GMSL2 is the right sat:** the sat is close (<15 m), you want RAW
into Thor ISP (tracking, SLAM, your own NVENC look), and you will pay
for FSYNC. Alvium GM2 / NileCAM81 / VC IMX585+GMSL adapter.

**When encode-on-sat is the right sat:** anything across a stage,
anything cheap, anything we already steered (hybrid fabric, T4000 HQ
cannot encode 1+2). This is the bring-up plant.

**Do both at the connector level, not as two products.** Body = CSI
(or one GMSL hop if the sensor sits 1–2 m off the box). Sats = PoE
H.265. Add a JCB022 later if a sat needs to become a RAW tracker.
Do not make every sat GMSL — you will run out of CSI lanes, ISP, and
NVENC before you run out of set.

HSB/CoE is the third path (RAW-class over Ethernet, FPGA on the
camera). Worth a later look; not cheap, not a $50 turret.

---

## What a “turret” is

CCTV housing slang, not a PTZ and not a tank:

| Shape | What |
|---|---|
| **Turret / eyeball** | Ball-and-socket. Lens sits in a sphere you twist by hand after the base is screwed to the wall. No bubble, so IR doesn’t bounce. The cheap 4K PoE cameras. |
| Dome | Same guts under a plastic bubble. Harder to aim, vandal-resistant. |
| Bullet | Long tube on a bracket. Deterrent shape, longer lenses. |

When we say “buy a turret,” we mean a complete **PoE + IMX415 + RV1126 + H.265 + ONVIF** camera in that eyeball shell, ~$50–150. Ethernet and hardware 4K encode are already in there. We do not want the shell as the product.

---

## Cheap hardware for Ethernet + hardware 4K H.265

Sat SoC is **Rockchip RV1126B** (newer) or **RV1126** (same job, cheaper stock). They are close enough that a turret on either silicon is a valid encode mule.

| SoC | Encode | Notes |
|---|---|---|
| **RV1126B** | H.265/H.264 4K30 (brochure 4K45 / 12 MP30, to 200 Mbps) | **Prefer.** 4× A53, 3 TOPS, **GbE**, USB3. Fanconn / Boardcon MINI1126B-P, EASY-EAI, G126BP-IPC modules. |
| **RV1126** | H.265/H.264 4K30 + 1080p30 second stream | 4× A7, 2 TOPS, ~5 W. Most $50 turrets. Fine if that’s what’s in the shell. |
| HiSilicon Hi3519A | 4K60, better ISP | Export-painful in the US. Skip unless a camera we already opened has it. |
| Ambarella CV2/CV5 | cinema-grade | Wrong price. |
| RK3588 | 4K encode *and* a desktop | Overkill; mini-PC size and watts. |

### Crack a turret vs buy a module (we make our own case)

| | **Crack a PoE turret** | **RV1126B IPC module / EVB** |
|---|---|---|
| First picture to Thor | **Hours.** RTSP/ONVIF, PoE, 4K30 H.265 already work. | Days. Flash SDK, wire sensor, bring up rkipc. |
| UART / GPIO | Usually **none** you can reach. Closed firmware, may phone home. | **Yes.** UART for /i and 1D ToF, GPIO, SDK. |
| Lens | Soldered M12. | MIPI CSI — C-mount / our glass later. |
| Lidar sidecar | You will fight the vendor image. | This is why we own the board. |
| Case | Their eyeball is junk for a set. We throw it away. | We were printing a case anyway. |
| Cost | **$50–150** complete | EVB **$160–244**; 38 mm core **$90–135** |

**Both.** One or two turrets this week as a known-good encode+PoE reference
(does Thor remux? does NVDEC decode for AD?). **The sat we ship is the
module in our case**, because Cooke /i and lidar need pins a sealed
turret will not give us. Cracking is not easier than an EVB once we
are fabricating the housing — it is only easier for the *first RTSP
packet*. Do not design the product around the board you pulled out
of a Hikvision-shaped shell.

| Buy | Street | Role |
|---|---|---|
| RV1126/B + IMX415 **turret**, PoE, ONVIF | **$50–150** | Encode mule. Crack, keep the PCB, bin the shell. |
| RV1126B **EVB** + IMX415 | **$160–244** | Software home. SDK, serial, Ethernet. |
| RV1126/B **38 mm core** | **$90–135** 1-off | Path to C-mount sat we own. |
| Boardcon MINI1126B-P | quote | Newer B silicon, GbE on module. |

Bitrate we haul: ~80 Mbps/cam 4K30 (STREAM-BUDGET). 3 sats ≈
0.24 Gbps. Gigabit PoE + Thor 5GbE is plenty. T4000 NVDEC 9× 4Kp30
is the AI ceiling, not the NIC.

---

## Lidar on the data cameras

Feasible. Not “a Livox on every $80 sat.”

| Tier | What | Street | On every sat? |
|---|---|---|---|
| **1D ToF** (Benewake TFmini-S / TF-Luna) | Subject distance, 0.1–12 m, UART, ~0.7 W, 10–40 g | **$25–45** | **Yes.** JSONL sidecar next to /i. Needs the module UART, not a sealed turret. |
| **2D spin** (YDLIDAR T-mini Plus) | 360° × 12 m, ~45 g, robot-vac class | **~$80** | No. Room layout, not picture-aligned depth. |
| **3D lidar** (Livox Mid-360S) | 360° × 59°, 200 kpts/s, **Ethernet**, 65 mm cube, **265 g** | **~$550** | **One on the rig**, not per camera. Another Ethernet endpoint on the PoE switch. |
| Stereo / iToF (Orbbec Gemini, etc.) | Depth image, GMSL or USB | $200–800 | Body, if we want occlusion better than Depth Anything. |

Working plant:

- **Body / rig:** one Mid-360S (or a stereo/ToF) as an Ethernet peer.
  Point cloud is a fourth “camera” on the switch. 905 nm Class 1 —
  still a laser on a film set; flag it.
- **Every picture sat:** TFmini-S on UART → distance in the sidecar.
  Cheap, metric scale for SLAM, not a point cloud.
- Thor already runs cuVSLAM + Depth Anything on the body HEVC/CSI.
  Per-sat 3D lidar does not replace that and does not fit the BOM.

Do not put 265 g / $550 on each eyeball. Do not skip the 1D ToF —
that is the “lidar on all data cameras” that actually ships.

---

## How big / heavy is Thor — and should it live in the camera body?

### The module (what production is)

| | mm | g | W |
|---|---|---|---|
| **T4000 SOM** (DS-11945 §6.4) | **87.0 × 100.0 × 15.29** | **350 ±4%** | 70 default / 90 throttle |
| ATS **passive** HS `ATS-NVP-3739` | 87 × 100.8 × **20** | **168** | 100 W @ 50 °C **with 500 LFM** (not still air) |
| ATS **active** HS `ATS-NVA-3740` | 87 × 100.8 × **20** (fan in fins) | **104** | 95 W @ 50 °C |
| ATS blower `ATS-NVA-3752` | 92 × 100.8 × 28.6 | 174 | 175 W — T5000-class, skip |
| **SOM + HS** | ~87 × 101 × **~36** | **~450–520** | still needs a carrier |

TTP contact patch is 62.5 × 81.4 mm. Resin is not a heat sink.
Full thermal math: [references/THERMAL.md](references/THERMAL.md).

### The carrier (you cannot skip this)

| | mm | g |
|---|---|---|
| CTI **Rogue-T5** AGX302 | **92 × 108** | **136** (product page; T4000 *and* T5000) |
| FORECR **DSBOARD-THRMAX** | **140 × 125** | — |
| NVIDIA **AGX Thor Dev Kit** | **243.19 × 112.40 × 56.88** | brick | 40–130 W, T5000. Lab only. |

**Rogue-T5 is the preferred carrier** (2026-09-02). Smallest
production board that takes T4000 *and* T5000; camera I/O is an
add-on (JCB022 GMSL, JCB003 3G-SDI, MIPI). 2× 10GbE + 2.5G on
locking IX plugs (need breakout cables). 12 V.

Rogue-T5 + T4000 + HS is the smallest catalog stack: about
**92 × 108 × 40–55 mm** plus connectors, **~0.7–1.0 kg** before
battery, lens, NVMe. FORECR is a bigger rectangle with QSFP.

### Against a cine body

| | mm | kg | W (picture) |
|---|---|---|---|
| **PYXIS 6K** body | 119 × 106 × 151 | **1.5** | ~15–25 class |
| T4000 + Rogue + HS (no lens, no batt) | ~92 × 108 × 50 | **~0.8–1.0** | **70** |
| AGX kit in our resin shell | 243 × 112 × 57 (+ walls) | kit + resin | 40–130 |

The SOM sandwich is **smaller in two axes than PYXIS and a lot
hotter.** PYXIS depth is the PL mount + sensor stack. Ours would
be: PL (or C) on the front, CSI flex 20 cm to Thor, heatsink
exhaust, V-mount on the back.

### Verdict: Thor-in-body is still the product shape — thermal is the hold

TDG-12271-001 v1.3 is in tree. Read [references/THERMAL.md](references/THERMAL.md)
before any solid body CAD.

**Coolest (and right) shape:** one box that *is* the camera.
T4000 + **Rogue-T5** + CSI body sensor + PL /i reader + NVENC
+ 10GbE. Sats are PoE H.265 on RV1126B, not more Thors.

**Do not put the AGX kit in a cine body.** 243 mm brick, 130 W.
The resin shell is a fit-check of the lab brick, not the product.

**Do not put a Thor in every sat.** $2,749 + 70 W + 350 g per
eyeball.

**Do not freeze a sealed handheld at 70 W.** NVIDIA allows a
passive *or* active cooler on the TTP. The math does not: 70 W
in still air needs ~0.55–0.69 °C/W, which a small extrusion is
not. A PYXIS-sized metal shell dumps ~40 W natural convection.
Prefer **radiators / heatpipes / vapor chamber**, not a flock of
fans:

1. Body-as-radiator, fanless — honest at **record-only / AI dropped
   (~15–40 W)**. Matches drop-AI-never-record.
2. Heatpipes to a rear / V-mount radiator + **one** large slow fan
   — 70 W AI. Cine already sounds like this.
3. Remote radiator on the battery plate — optical body silent.

Measure T4000 + Rogue-T5 + ATS on the bench (thermocouple on TTP
per TDG Fig. 3-2) before promising sun-load or a magnesium shell.
Lab stays the AGX kit. Production body is **metal**. Those are
two different objects; do not confuse the CAD.

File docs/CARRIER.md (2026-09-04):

---
title: "Carrier"
kicker: "Compute"
group: "hardware"
summary: "Lab brick is the AGX Thor Developer Kit (T5000). Production ceiling is the T4000 SOM — 64 GB, 1× NVENC, 70 W default — unless satellite count forces T5000."
---

# Carrier

Activated with `aicam-thor-carrier`. Spec: `openspec/changes/add-thor-carrier/`.
Module facts: [references/T4000.md](references/T4000.md).

## Lab brick

**Jetson AGX Thor Developer Kit** = T5000 module.

- 243.19 × 112.40 × 56.88 mm (kit, not SOM)
- 128 GB, 2× NVENC, 40–130 W
- 1× 5GbE RJ45, 1× QSFP28 (4 independent 25G, not 100G aggregated)
- 2× USB-A 3.2, 2× USB-C 3.1
- HSB via QSFP, USB cameras
- First enclosure wraps **this** brick

## Production SOM

**T4000** (DS-11945-001 v1.4):

- 87.0 × 100.0 × 15.29 mm, 0.350 kg ±4%, 699-pin B2B
- 64 GB LPDDR5X, 273 GB/s, 12× Neoverse V3AE, 1536 CUDA
- 1× NVENC / 1× NVDEC / 1 ISP
- 3× 25G MGBE (75 Gbps total, independent)
- Rails: SYS_VIN_HV 7–20 V (typ 12 V), SYS_VIN_MV 5 V. **No** SYS_VIN_SV, **no** CAN
- Default 70 W, throttle at 90 W TMP, TTP max 75 °C

Stay on T4000 unless satellite count forces T5000 encode.

**Preferred carrier (2026-09-02): Connect Tech Rogue-T5 (`AGX302`)**,
92 × 108 mm, T4000 and T5000, camera I/O via JCB add-ons. See
[SHOPPING.md](SHOPPING.md). Thermal: TTP cooler is customer-side;
[references/THERMAL.md](references/THERMAL.md).

## Carrier I/O the body needs

- CSI-2 (or GMSL deserializer) for the **body** camera
- MGBE copper/fiber to a **PoE switch** (switch is not on the SOM)
- NVMe
- TTP cooler per [references/THERMAL.md](references/THERMAL.md) (TDG-12271-001 v1.3 in tree)
- 7–20 V input that does not backfeed from PoE

Partner boards with 8× GMSL2 (e.g. Firefly EC-ThorT5000) are T5000-class
and GMSL-first. Only buy one if we abandon T4000 ceiling or need GMSL sats.

## Still need

- DG-12084-001 Design Guide
- AGX kit datasheet PDF
- P3834 STEP model (metal body fit)

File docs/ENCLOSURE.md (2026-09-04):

---
title: "Enclosure"
kicker: "Shell"
group: "hardware"
summary: "First article wraps the AGX kit, two-part resin for an Anycubic bed. Resin is a fit-check, not a heat sink. Production body is metal — the radiator."
---

# Enclosure

Activated with `aicam-enclosure`. Spec: `openspec/changes/add-thor-enclosure/`.
Print: `aicam-print` (human, Anycubic resin).

## First article

Wrap the **AGX Thor Developer Kit**, not the SOM:

- 243.19 × 112.40 × 56.88 mm
- Leave kit fan / TTP path open
- Boss or clamp for the **body camera** on the front
- Cable exits: 5GbE, QSFP, USB-C, power, body CSI/GMSL if present

Production SOM lid is a **later metal** article, not resin. Product
shape is still **Thor inside the camera body** (T4000 + **Rogue-T5** +
CSI sensor), not the AGX kit and not a PYXIS bolted onto a brick.
Thermal architecture is a **hold** until we measure T4000 + Rogue-T5 +
ATS on the TTP (TDG-12271-001 v1.3): prefer heatpipes / vapor chamber /
a real radiator over lots of fans. 70 W fanless in a cine envelope is
not honest; record-only / drop-AI is. See
[references/THERMAL.md](references/THERMAL.md) and [CAMERAS.md](CAMERAS.md).
Sats stay off-body PoE.

## CAD (first article, 2026-09-01)

Blender 5.0 via addon socket `:9876` (Grok MCP blender server was not
in this session; same protocol). Script: [cad/build_agx_shell.py](cad/build_agx_shell.py).

| File | What | Span (mm) |
|---|---|---|
| [cad/agx_thor_shell.blend](cad/agx_thor_shell.blend) | Kit dummy + two halves | — |
| [cad/agx_shell_front.stl](cad/agx_shell_front.stl) | Camera-boss half | **152.3 × 119.8 × 64.3** |
| [cad/agx_shell_rear.stl](cad/agx_shell_rear.stl) | Cable-exit half | **130.3 × 119.8 × 64.3** |
| [cad/preview.png](cad/preview.png) | Viewport | — |

Wall 2.2 mm, 1.5 mm kit clearance. Front has a 32 mm OD / 18 mm bore
boss. Rear has RJ45 / QSFP / DC cutouts. Top vent slots. Manifold.

**Print:** two parts so they fit a ~192 × 120 mm resin bed. Width **119.8 mm**
is tight on a 120 mm vat — rotate or knock 0.5 mm off the walls if the
slicer complains. Resin is a fit-check, not a heat sink. Leave the TTP
path open.

Production SOM lid is metal, after a TTP measurement, not this resin print.

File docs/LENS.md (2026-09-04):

---
title: "Lens metadata"
kicker: "Cooke /i"
group: "hardware"
summary: "Frame-accurate /i (or LDS / XD / EF electronic) from every camera, written as JSONL next to picture. Maps live on the NAS, not per frame."
---

# Lens metadata — Cooke /i class

Every camera, body and satellite, emits frame-accurate lens data next
to picture. Interchange is **Cooke /i** (and /i3 shading/distortion
maps). ARRI LDS and ZEISS eXtended Data are cousins; we normalize to one
sidecar.

Product ground already says the record path carries “lens” in the
sidecar (`web3d-space` MODES.md). This file says **what** that is.

## What /i actually is

Cooke /i Technology: electronics in the lens, absolute encoders, no
init dance. Pins in the PL mount (12 o’clock) and/or an external /i
port on the barrel. License to speak it is €1/year for manufacturers.

Per frame, up to 285 fps:

| Field | Why we want it |
|---|---|
| Manufacturer, type, serial | Continuity, which glass |
| Focal length (true, not the barrel number) | Intrinsics, matchmove |
| Focus distance | DoF, VFX, AD notes |
| T-stop | Exposure, DoF |
| Zoom position / normalized zoom | Zooms |
| Near / far focus, hyperfocal | Scripty / AD |
| Horizontal FOV | Coverage / splat-readiness |
| Entrance pupil | Nodal / virtual camera |
| /i3 shading + distortion maps | Post; **not** every frame — file once per lens+setting |

Metric or imperial, camera’s choice; we store SI in the sidecar.

## Transport (each camera)

Picture is HEVC. Lens data is a **second stream**, 1:1 with encoder
timecode, same as pose. It is not in the 80 Mbps HEVC budget.

```
lens /i pins or /i port
        │
        ├─ body: PL contacts or barrel port → UART/USB on Thor
        │
        └─ sat:  barrel port → /i-to-Ethernet bridge (e.g. Ambient Lockit+
                 TCP 3001 YAML or 3002 raw /i3)
                 OR camera embeds /i in SDI VANC / ONVIF metadata
                          │
                          ▼
              Thor writes JSONL sidecar next to the HEVC
              {camera_id, tcode, ...fields}
```

Do not rely on the scripty typing T-stop. If a camera cannot speak /i,
LDS, XD, or EF electronic iris+focus, it is a **bring-up stub**, not a
hero sat.

## Shopping implication

Cheap PoE boxes with P-iris counts are not /i. Satellites that must
send Cooke-class data need cine glass (/i, LDS, or XD) plus a reader,
or a cinema camera that already muxes /i into its files.

Body: PL or LPL with /i+LDS pins, or EF with electronic metadata as a
fallback (focal + iris + focus, no entrance pupil).

## Sidecar (record)

One JSONL line per sample, timecode-locked to that camera’s HEVC:

```json
{"cam":"A","tc":"01:02:03:04","make":"Cooke","model":"S7/i 32","sn":"…",
 "fl_mm":31.7,"focus_m":2.13,"t":2.8,"zoom_n":null,
 "near_m":1.9,"far_m":2.4,"hyper_m":12.1,"hfov_deg":39.4,"ep_mm":87.0}
```

Maps (/i3 distortion, shading) live as files on the NAS keyed by
`make/model/sn`, referenced from the sidecar, not dumped per frame.

## Still open

- Reader hardware on the Thor carrier (PL contacts vs barrel-only)
- Lockit+ vs in-camera /i vs EF for bring-up
- Whether we store /i3 maps at slate time or from a lens library

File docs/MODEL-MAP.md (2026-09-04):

---
title: "Model map"
kicker: "Stages 0–19"
group: "hardware"
summary: "Index of which job runs on Thor vs the 6000. Thor resident set stays ≤ ~40 GB. If the 6000 is off, stages 0–8 and 19 still complete."
---

# Model map — pipeline stages on this kit

Index only. Canonical placement, licenses, and VRAM live in

`~/work/Family/web3d-space/docs/all-systems-go/MODELS.md`

Pipeline stages: `…/PIPELINE.md`. Modes: `…/MODES.md`.

Latency: **LIVE** &lt;33 ms · **NEAR** 1–30 s · **MIN** minutes · **NIGHT** hours.

Thor resident set stays ≤ ~40 GB. Always: NVENC + cuVSLAM + (SAM2 **or** Maxine) + Depth Anything V2-S. Pick one extra (AD 9B / AD 27B / klein snap / AR overlay). Drop AI, never record.

If the 6000 is off, stages **0–8 and 19** still complete.

## Stages 0–19

| # | Stage | Default model / engine | Box | Latency | On Thor? |
|---|---|---|---|---|---|
| 0 | Power-on / rig | load encode + SLAM + 9B or klein; thermal | Thor | — | yes |
| 1 | Scout | cuVSLAM sparse map; optional VGGT burst | Thor; VGGT on 6000 | LIVE / NEAR–MIN | SLAM yes; VGGT no as 24 fps |
| 2 | Previs / block | USD mesh occluders + live pose | Thor | LIVE | yes, mesh not splat-fill |
| 3 | Light / look | LUT; **FLUX.2 klein 4B** snap | Thor | NEAR | snap mode; unload 27B |
| 4 | Slate | sidecar JSON + burn-in | Thor | LIVE | yes |
| 5 | Capture | NVENC all Thor-side cams; sat HEVC remux; pose; NAS write-through | Thor | LIVE | encode always |
| 6 | Live AD | **Qwen3.5-9B** (27B on sticks, 130 W) | Thor | NEAR | yes; 27B unloads klein |
| 7 | Live AR | depth-test mesh / low splat, **not** a DiT | Thor | LIVE | 720p EVF honest; 4K photoreal splat not v1 |
| 8 | Playback / continuity | NVDEC last-take; VLM index | Thor + NAS | NEAR | yes |
| 9 | Dailies / proxy | proxies, waveform | **6000** + NAS | MIN | no |
| 10 | Reconstruct | COLMAP **or** VGGT shared poses | **6000** | MIN | no |
| 11 | Appearance | **gsplat** (Apache) | **6000** | MIN–NIGHT | no |
| 12 | Structure | Meshroom / OpenMVS or Scaniverse LiDAR | 6000 / phone | MIN–NIGHT | no |
| 13 | Author USD | SOG/SPZ + GLB + `KHR_gaussian_splatting` | 6000 + web3d-space viewer | MIN | no |
| 14 | Matchmove lock | **recorded pose sidecar** first; else VGGT/COLMAP | Thor record / 6000 solve | — | record yes |
| 15 | Performance transfer | live: Maxine/SAM2; hero: **4DGS** | Thor live / **6000** night | LIVE / NIGHT | live bones only |
| 16 | Plate ↔ scene | depth-test LIVE; Cosmos-Transfer / Wan MIN | Thor / **6000** | LIVE / MIN | composite yes; DiT no |
| 17 | Generative insert | FLUX.2 [dev]; Wan 2.2; Hunyuan 1.5; H3 if licensed | **6000** | MIN | **no** |
| 18 | Grade / deliver | ProRes/EXR and/or SOG+GLB+USD | 6000 + viewer | MIN | no |
| 19 | Archive / exit | NAS disks: keys, takes, prompts, LUTs, scenes | NAS | — | cache only |

## Named jobs you asked about

| Job | Model | Where | What it is not |
|---|---|---|---|
| **Snap / inline still** | FLUX.2 [klein] 4B Apache (~8–13 GB) | Thor, snap profile | Not a replacement take. Unloads 27B. klein 9B is non-commercial. FLUX.2 [dev] is 6000. |
| **Performance tracking** | SAM2 (TensorRT) + Maxine 3D body (34 kpts) | Thor | Not a VLA. One or the other at 4K until measured. |
| **Performance capture (live)** | Maxine/SAM2 → bone stream to USD humanoid | Thor | Blocking and eyeline. OpenPi π0.5 only if the body is a motion-control head. |
| **Performance transfer (hero)** | 4DGS train overnight | **6000** | Not live. Markers optional. |
| **Shot-calling** | Qwen3.5-9B (~7–12 GB) | Thor | Talks; does not move the camera unless asked. |
| **Pose / matchmove** | cuVSLAM + IMU, 1:1 sidecar with picture | Thor always | VGGT is a burst reconstructor, not 24 fps. |

## Never resident on Thor

MiniMax H3, Wan 2.2 14B, Hunyuan, Cosmos-Predict 14B, Cosmos-Transfer2.5 (~65 GB FACT), TRELLIS.2 high res, room-scale gsplat densify, FLUX.2 [dev] BF16.

H3: US open-weights excluded. Default local video for a US artist is Wan 2.2 + Hunyuan 1.5 + Cosmos. H3 is a license gate or API.

## License defaults (from MODELS.md)

**Ship:** gsplat, COLMAP, Wan 2.2 5B, FLUX.2 klein 4B, Isaac ROS / cuVSLAM, PlayCanvas, SAM2 (check Meta), Qwen3.5 (check current terms).

**Gate:** FLUX.2 [dev] / klein 9B, INRIA 3DGS, Hunyuan community, MiniMax H3.

## Thor co-resident extra (one at a time)

| Profile | Extra | Unload |
|---|---|---|
| AD | Qwen3.5-9B | — |
| AD heavy | 27B | klein |
| Snap | klein 4B | 27B |
| AR overlay | mesh + low splat | klein + 27B; keep 9B if AD talks |

MIG: slice 0 = encode + SLAM. Slice 1 = brain. Kill slice 1 first.

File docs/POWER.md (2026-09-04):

---
title: "Power"
kicker: "Watts"
group: "hardware"
summary: "T4000 default 70 W, throttle at 90 W. If power sags: drop AI, never record. Two PoE+ sats ≈ 60 W at the PSE. Do not power Thor from the switch."
---

# Power and thermal

Activated with `aicam-thermal`. Spec: `openspec/changes/add-power-thermal/`.
If power sags: **drop AI, never record**.

## Thor

| | T4000 SOM | AGX kit (T5000) |
|---|---|---|
| Default | 70 W | 120 W mode exists; kit 40–130 W |
| Throttle | TMP > **90 W** | TMP > 130 W |
| TTP max | **75 °C** | 80 °C |
| HV | 7–20 V (12 V typ), 22 A max @ 20 V | kit brick |
| MV | 5 V, 6 A max | kit brick |
| SV 3.3 V | none | T5000 only |

TDG-12271-001 v1.3 is in tree: [references/THERMAL.md](references/THERMAL.md).
T4000 TTP **75 °C**, SoC 90 °C recommended. 70 W still-air handheld
is not honest; body-as-radiator ~40 W; 70 W AI wants heatpipes to a
real radiator and at most one slow fan. Prefer radiators to lots of
fans. Measure before sun-load promises.

## PoE satellites

Two cameras at 802.3at ≈ **60 W** at the PSE. Heated/PTZ → bt.

PoE switch is its own PSU. Do not power Thor from the switch.

## Kit watts (bring-up order of magnitude)

- AGX Thor: 40–130 W
- 2× PoE+: ~60 W
- Switch: ~15–30 W
- NAS: off-body

## Enclosure

Resin is structural, not a heat sink. Vent the TTP / kit fan. First
print is a fit-check of the **AGX kit** (243 × 112 × 57 mm), not the
15 mm SOM sandwich. Production body is **metal** (the radiator).
Hold sealed-body CAD until T4000 + Rogue-T5 + ATS is measured.

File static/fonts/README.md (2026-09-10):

# Bay HUD type

- `space-age.ttf` — display / lock-in (Duke library)
- `TacticSansExtExd-Blk.otf` — HUD digits
- `TacticSans-Reg.otf` — HUD labels

These are Duke's licensed copies, committed so `/bay` prerenders. Confirm web-embed rights before treating GitHub Pages as a public type foundry. Not an OSI license.

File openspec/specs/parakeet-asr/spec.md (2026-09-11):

# parakeet-asr

Living spec for CPU-only Parakeet ASR on the tailnet. In-flight
deltas: `openspec/changes/*/specs/parakeet-asr/`.

## Purpose

Agents discover a generated OpenAPI 3.1 document at a well-known URL,
then POST a clip or stream 16 kHz mono PCM. Pages cannot host this.
A standalone Bun + Hono process on the tailnet can; the 3090 stays on
30 fps plugins.

## Requirements

### Requirement: Well-known OpenAPI
The ASR process SHALL publish the current OpenAPI 3.1 document at
`GET /.well-known/openapi.json`. The body SHALL be the same bytes as
`GET /api/v1/openapi.json`. The document SHALL set `servers` to the
`/api/v1` base so path keys are relative to it. `GET /.well-known/api-catalog`
SHALL be an RFC 9727 linkset pointing at those two URLs. The well-known
URL SHALL NOT return HTML. Agents SHALL discover operations from this
document, not from a hardcoded route list.

#### Scenario: agent discovers the API
- GIVEN the ASR process is bound on the tailnet
- WHEN an agent `GET /.well-known/openapi.json`
- THEN the response is OpenAPI 3.1 JSON, `servers` includes `/api/v1`,
  and `paths` lists `/transcribe` and `/health` relative to that base

#### Scenario: well-known matches versioned
- GIVEN the generated spec
- WHEN `GET /.well-known/openapi.json` and `GET /api/v1/openapi.json`
- THEN the two bodies are identical

#### Scenario: curl well-known
- GIVEN the Bun process is up on the tailnet
- WHEN `curl -sf http://100.103.147.70:8750/.well-known/openapi.json`
- THEN `openapi` starts with `3.`, `servers` includes `/api/v1`, and
  `paths` includes `/transcribe` and `/health`

### Requirement: Bun Hono REST
The ASR HTTP surface SHALL be a standalone Bun process using Hono and
`@hono/zod-openapi`. Features SHALL land as `createRoute` operations
before any other client. The process SHALL NOT be mounted inside the
SvelteKit `adapter-static` app.

#### Scenario: spec first
- GIVEN a new transcribe field
- WHEN it is callable
- THEN it appears in `/.well-known/openapi.json` from the Zod route

### Requirement: CPU-only Parakeet
Transcription SHALL run NVIDIA Parakeet TDT 0.6B v3 INT8 on CPU
(`CPUExecutionProvider`). The sidecar SHALL run with `CUDA_VISIBLE_DEVICES`
empty and ONNX Runtime intra-op threads ≤ 4. The ASR process and sidecar
SHALL NOT create a CUDA context. The 3090 SHALL remain available for 30 fps
plugins.

#### Scenario: transcribe leaves the GPU idle
- GIVEN compositor-only VRAM (~319 MiB)
- WHEN a clip is transcribed
- THEN `nvidia-smi` memory.used is unchanged and no python/onnx CUDA process appears

#### Scenario: transcribe beside 30 fps plugins
- GIVEN the 30 fps plugin stack is running on the 3090
- WHEN a clip is transcribed on the sidecar
- THEN intra-op threads stay ≤ 4 and plugin frame time does not regress from the CPU steal

### Requirement: Tailscale bind
The ASR process SHALL bind the Tailscale IPv4 only (default
`100.103.147.70:8750`) and SHALL NOT listen on `0.0.0.0`. The sidecar
SHALL NOT open a network listener; it is a child of the Bun process on
stdin/IPC. Bun SHALL be the sole tailnet socket.

#### Scenario: no public bind
- GIVEN the unit is running
- WHEN `ss` or `lsof` lists the ASR port
- THEN the listen address is the Tailscale IP, not `0.0.0.0` or `*`

#### Scenario: sidecar has no port
- GIVEN the sidecar is warm
- WHEN listeners on the box are listed
- THEN only Bun holds `:8750` on the Tailscale IP; the sidecar has no TCP/UDP bind

### Requirement: Clip transcribe
`POST /api/v1/transcribe` SHALL accept 16 kHz mono audio (WAV or raw
PCM as declared in the spec) and return JSON with the transcript text.
A warm sidecar SHALL serve the second call without reloading weights.
Wrong sample shape SHALL be 422. Non-audio content-type SHALL be 415.
Sidecar unavailable SHALL be 503. `GET /api/v1/health` SHALL report
sidecar `warm | cold | down`, provider `CPUExecutionProvider`, and
model id, and SHALL be listed in the well-known document.

#### Scenario: known wav
- GIVEN `2086-149220-0033.wav` and a warm sidecar
- WHEN `POST /api/v1/transcribe`
- THEN the body includes text about Phoebe and the old portrait

#### Scenario: health before a clip
- GIVEN the sidecar is warm
- WHEN `GET /api/v1/health`
- THEN the body says `warm`, provider is `CPUExecutionProvider`, and
  the well-known spec lists `/health`

### Requirement: Audio stream pipe
The API SHALL accept a 16 kHz mono PCM stream and emit transcript
segments as NDJSON `{text, t0, t1, final}`. Windowed TDT (VAD or
fixed windows) is the v1 decoder. v1 stream clients are non-browser.
The stream operation SHALL appear in `/.well-known/openapi.json`.
End-of-stream is connection close; the last event SHALL set `final: true`.

#### Scenario: pipe PCM
- GIVEN a 16 kHz mono PCM stream of spoken English
- WHEN a client opens the stream operation
- THEN NDJSON text events arrive without a CUDA process on the 3090

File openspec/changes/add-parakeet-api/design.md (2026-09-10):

# Design: parakeet-asr

## Process split

GitHub Pages is static. The ASR API is a **Bun** process on fractal1,
sibling to `aicam-bay-feed` (`:8745`), bound to the Tailscale IPv4 only
on **`:8750`**. UPnP is on; never `0.0.0.0`.

```
caller --HTTP--> Bun Hono :8750  --stdin/IPC-->  Python onnx-asr sidecar
                 OpenAPI here                    INT8 TDT v3, CPU EP
```

Hono owns HTTP, Zod, and the spec. The sidecar owns the model. Bun does
not `dlopen` CUDA. The sidecar sets `CUDA_VISIBLE_DEVICES=` and
`providers=["CPUExecutionProvider"]`. Four intra-op threads.

Papyrus `morphist-asr` is the policy source (CPU-when-AVX2, 16 kHz mono
f32, INT8 ONNX, keep the dGPU free). It is utterance-batch, CoreML on
Apple, and a Tauri crate. We do not vendor it.

## Discovery

Copy daBOM, not the SvelteKit mount:

| URL | Body |
|---|---|
| `GET /.well-known/openapi.json` | OpenAPI 3.1, canonical; `servers: [{ url: '/api/v1' }]` |
| `GET /api/v1/openapi.json` | same bytes |
| `GET /.well-known/api-catalog` | RFC 9727 linkset |

`app.doc31('/openapi.json', …)` generates the document from
`createRoute`. Agents read well-known. Do not hard-code path lists in
clients in this repo.

## Audio

Input is 16 kHz mono PCM (or WAV that already is that). Wrong sample
shape is 422. Non-audio content-type is 415. The sidecar does not
resample or mix channels. Clip `POST` is one utterance. Stream is
windowed TDT (VAD or N-second chunks) emitting NDJSON
`{text, t0, t1, final}`. v1 stream clients are non-browser. No Unified
RNNT in this change.

The sidecar is a child of the Bun process on stdin/IPC. It does not
open a network listener. Bun is the sole tailnet socket.

## GPU

A new CUDA process during transcribe is a failed acceptance, not a
warning. Bay feed stays the 3090 tenant.

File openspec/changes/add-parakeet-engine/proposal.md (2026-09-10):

# add-parakeet-engine

> **ACTIVE BUILD**

## Why

Hono must talk to a warm CPU Parakeet, not cold-start onnx-asr per
request (first load was ~40 s). The 3090 stays on plugins.

## What

- Long-lived INT8 TDT 0.6B v3 sidecar on fractal1
- `CPUExecutionProvider`, `CUDA_VISIBLE_DEVICES` empty, 4 threads
- Transcribe a WAV; second call does not reload weights
- Capability: `parakeet-asr`

## Impact

- Capabilities: MODIFIED `parakeet-asr` (engine)
- ADRs: none

## User journey & surfaces

Bun calls the sidecar. No new UI because the surface is the REST process.

## Out of scope

- HTTP/OpenAPI (`add-parakeet-hono`)
- PCM stream windows (`add-parakeet-stream`)
- CUDA / NeMo / NIM

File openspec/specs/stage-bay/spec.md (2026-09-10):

# stage-bay

Living spec for the hardware notebook bay: fractal1 brick state as a
Tailscale-only JSON feed. In-flight deltas: `openspec/changes/*/specs/stage-bay/`.

## Purpose

`/bay` needs a JSON snapshot of fractal1 without SSHing. Bind like SMB:
Tailscale IP only. GitHub Pages never calls the feed.

## Requirements

### Requirement: Tailscale-only loadout feed
Fractal1 SHALL serve `GET /loadout.json` on `100.103.147.70:8745` and
SHALL NOT bind that port on `0.0.0.0`. The body SHALL include gpu, ram,
swap (zram vs swapfile), procs, and stack with resident flags.

#### Scenario: GET from the Mac
- GIVEN the unit is active and Tailscale is up
- WHEN `curl -sf --max-time 3 http://100.103.147.70:8745/loadout.json`
- THEN the response is JSON with `gpu.vram_used_mib` and `swap.disk_used_mb`

### Requirement: Bay glass reads as an EVF
`/bay` SHALL present VRAM, power, RAM, zram vs disk swap, and the model
mag rack in a dark EVF chrome (tungsten, tally, waveform). It SHALL NOT
use the docs paper-grid as the primary surface.

#### Scenario: idle brick plate
- GIVEN last plate or live idle snapshot
- WHEN `/bay` renders
- THEN VRAM readout, waveform fill, and mag rack are visible on a dark field

### Requirement: Bay is its own section
The hardware notebook SHALL expose brick state at `/bay`, a nav sibling
to Kit and Docs, not a mdsvex docs chapter.

#### Scenario: filmmaker opens Bay
- GIVEN the notebook
- WHEN they follow Bay in primary nav
- THEN they reach `/bay/` and the glass is the EVF, not a markdown article

### Requirement: Dark-locked glass
`/bay` SHALL render in its dark EVF palette regardless of the site light/dark toggle.

#### Scenario: site is in light theme
- GIVEN `data-theme=light` on the document
- WHEN `/bay` is shown
- THEN the bay surface stays dark (tungsten, tally, near-black)

### Requirement: Live on the tailnet, plate on Pages
Live metrics SHALL be fetched only from a same-origin vite proxy or a
Tailscale-bound HTTP feed. GitHub Pages SHALL display a committed last
plate. The feed SHALL NOT listen on `0.0.0.0`.

#### Scenario: Pages visitor
- GIVEN a public Pages build
- WHEN `/bay` loads
- THEN the glass shows the last plate, not a failed fetch to `100.x`

#### Scenario: vite on the tailnet
- GIVEN `npm run dev` and fractal1 reachable
- WHEN `/bay` loads
- THEN the glass updates from `/bay-api/loadout.json`

### Requirement: Swap split
The glass SHALL distinguish zram (compressed RAM) from the disk swapfile.
It SHALL NOT label zram as “swapping to disk.”

#### Scenario: idle brick
- GIVEN zram ~100 MB and swapfile ~7 MB
- WHEN the glass renders swap
- THEN disk paging is the swapfile number and zram is labeled as compressed RAM

### Requirement: Stack vs resident
The glass SHALL show the 3090 stack (SAM2-tiny, CLIP, FLUX.2 klein 4B)
as resident only when a live snapshot says so; otherwise on-disk / on the cart.

#### Scenario: idle after unload
- GIVEN no python CUDA process
- WHEN the mag rack renders
- THEN SAM2, CLIP, and klein read as on the cart, not loaded

### Requirement: HUD type
Bay titles SHALL use Space Age. HUD numerals SHALL use Tactic Extra
Extended Black.

#### Scenario: VRAM readout
- GIVEN a VRAM used figure
- WHEN it is painted
- THEN the digits are Tactic Extra Extended Black

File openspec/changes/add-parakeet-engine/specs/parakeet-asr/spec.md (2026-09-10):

## ADDED Requirements

### Requirement: Warm CPU sidecar
The ASR engine SHALL keep Parakeet TDT 0.6B v3 INT8 loaded in a
long-lived process. A second transcribe of the same clip SHALL NOT
reload encoder weights. Inference SHALL use ONNX Runtime
`CPUExecutionProvider` only.

#### Scenario: two clips
- GIVEN the sidecar has already transcribed one wav
- WHEN a second wav is sent
- THEN wall time excludes model download and GPU memory.used is unchanged

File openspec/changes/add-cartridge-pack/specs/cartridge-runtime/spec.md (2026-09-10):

## ADDED Requirements

### Requirement: Packer function
The kit SHALL expose a pure packer: desired cartridge ids and an
envelope id in, `{resident, refused, evict, log}` out, with no GPU.
Default envelope on fractal1 SHALL be `3090`. Envelope `t4000` SHALL be
a second call and SHALL NOT be reported as seated on the 3090.

#### Scenario: snap on fractal1
- GIVEN desired set is the snap preset
- WHEN the packer runs with envelope `3090`
- THEN klein-4b is resident if it fits; qwen-27b is not in the set

### Requirement: Record-path properties
A pack SHALL NOT drop always-on encode or cuVSLAM (except always-on
null → absent). Exclusive-tag collisions SHALL refuse and name what
to unslot. Over-ceiling SHALL refuse. A sag signal SHALL fill `evict`
with slottable AI and SHALL NOT list encode or cuVSLAM.

#### Scenario: sag
- GIVEN a seated set that includes klein-4b
- WHEN sag is signalled
- THEN evict contains klein-4b and does not contain nvenc-hevc

#### Scenario: 4K exclusive
- GIVEN sam2-4k and maxine-4k both requested
- WHEN the packer runs
- THEN the pack refuses and names the `sam2-maxine-4k` pair

#### Scenario: 3090 swap-set
- GIVEN klein-4b, sam2-tiny, and clip on envelope `3090`
- WHEN the packer runs
- THEN the pack seats if always-on plus the largest slottable peak fits

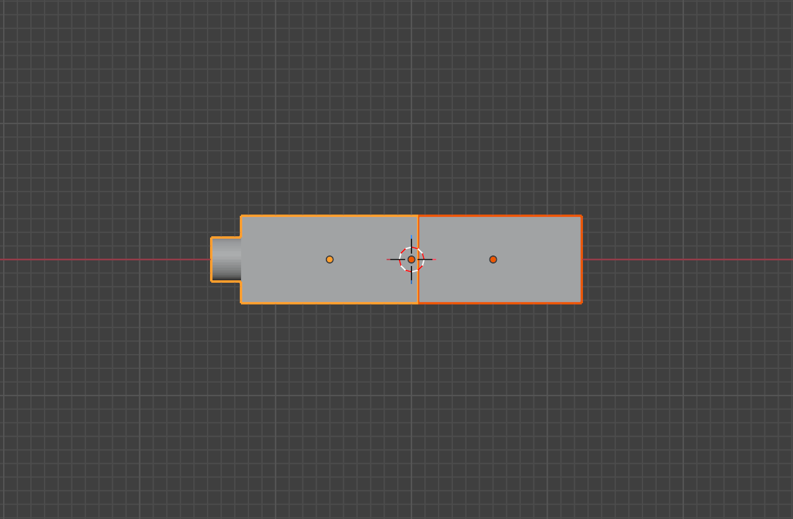
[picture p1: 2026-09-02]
docs/cad/preview.png

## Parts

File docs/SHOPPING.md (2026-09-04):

---
title: "Shopping"
kicker: "Buy brief"
group: "hardware"
summary: "Not a spec. Blackmagic is a cinema body (path B), not a CSI science project. T4000 SOM, AGX kit, and carrier options with street prices as of 2026-09-01."
---

# Hardware shopping — cameras and T4000 breakout

Prices checked 2026-09-01 (USD street unless noted). Confirm before you click.
This is a buy brief, not a spec. Product decisions stay in INTERCONNECT / SENSORS / LENS.

## The fork that matters

Blackmagic cameras **do not speak MIPI CSI**. They speak HDMI (Pocket / Cinema Camera 6K) or **12G-SDI + Ethernet + USB-C** (PYXIS). Thor eats CSI/GMSL/HSB natively.

So “mount a Blackmagic on the Thor box” has three honest paths:

| Path | 4K into Thor? | Cooke /i? | Crack the camera? | Prototype speed |
|---|---|---|---|---|
| **A. HDMI/SDI → CSI capture card on the carrier** | HDMI 4K30 maybe; **CTI JCB003 is 3G-SDI = 1080p60 only** | From BMD files / Ethernet control, not from the SDI payload | No | Days if the card exists for Thor |
| **B. BMD records BRAW internally; Thor gets a monitor feed + sidecar** | Thor AI on 1080p/4K HDMI proxy; master stays on CFexpress | Yes, in BRAW metadata (PL /i or EF/L electronic) | No | Fastest cine path |
| **C. Open the body, rewire the sensor to CSI** | Only if you reverse a Sony IMX + FPGA. Not a weekend. | You’d still need the /i pins off the mount PCB | Yes | Weeks–months. Don’t buy a PYXIS *in order* to do this |

**Recommendation:** do **not** buy a Blackmagic as a CSI science project. Buy it as a cinema body (path B, plus HDMI/SDI into Thor for live AD/overlay). If you want native CSI, that’s a FRAMOS/Leopard module, not BMD.

---

## 1. Compute / breakout (no custom PCB)

### NVIDIA Jetson T4000 SOM (the module)

| | |
|---|---|
| PN | `900-13834-0000-000` |
| Price | **$2,749** qty 1 at [Arrow](https://www.arrow.com/en/products/900-13834-0000-000/nvidia) (492 listed in stock, “ships tomorrow”; also lists 24-week factory LT) |
| 1KU list | Was $1,999; NVIDIA raised to **$2,999** (Jul 2026) |
| Notes | 64 GB, 1× NVENC, 70 W default / 90 W TMP, **no CAN, no 3.3 V SYS_VIN_SV**. Needs a 699-pin carrier + TTP/heatsink. Arrow already sold you the datasheet. |

ATS Thor heatsinks at Digi-Key: active **~$106**, passive **~$47**.

### NVIDIA AGX Thor Developer Kit (T5000 brick — not a T4000)

| | |
|---|---|
| PN | `945-14070-0080-000` (US) |
| Price | **$3,499** Arrow (75 listed); NVIDIA US list hiked to **$5,499** Jul 2026; Seeed industrial PDF **$5,899**; Amazon third-party **$2,799** — treat Amazon as unverified |
| What’s in the box | T5000 SOM, reference carrier, 140 W PSU, 1 TB NVMe, Wi-Fi, fan |
| I/O | 5GbE, QSFP28 (4× **independent** 25G, not 100G), HDMI **out**, DP, USB-C, HSB, USB cameras |
| Notes | Fastest software bring-up. **No HDMI/SDI in.** Wrong envelope vs production T4000. Fine as the lab brick we already designed the resin shell around. |

### Connect Tech Rogue-T5 (`AGX302`) — T4000 *and* T5000  **(preferred carrier)**

| | |
|---|---|
| Size | **92 × 108 mm** |
| Compat | T5000 / T4000 / IGX Thor 500 (no SMCU) |
| Net | 2× 10GBASE-T + 1× 2.5G, locking IX Industrial |
| Camera | Expansion header → add-on boards: GMSL2/3, **3G-SDI**, HDMI, MIPI, FPD-Link |
| Carrier-only | PN `AGX302` — **quote** `sales@connecttech.com` (not a web cart) |
| Integrated (T5000 already on board) | WDL: **$8,225–$12,325** depending on cooling/NVMe/Wi-Fi/GMSL ([example AGX302-01M $8,225](https://www.wdlsystems.com/embedded/gpgpu/custitem_ff_processor/Jetson-Thor,NVIDIA-Quadro)) |
| Power | 12 V, CTI brick MSG103 252 W |
| Notes | Smallest *production* Thor carrier. Same board if you later drop in T4000. Camera I/O is **add-on**, not on the carrier. Manual: CTIM-00160. |

### Connect Tech Gauntlet (`AGX301`)

| | |
|---|---|
| Size | 155 × 126 mm |
| Compat | Marketed T5000; T4000 support claimed in CTI blogs |
| Net | 2× 10GbE + 2× 1GbE RJ45 |
| Camera | 16-lane MIPI header + same JCB add-ons |
| Price | AU listing **A$3,999** (~US$2,600) “in stock” — confirm if that’s carrier-only or with T5000. US is quote/WDL assemblies |
| Notes | Bigger than Rogue-T5. Dual NVMe. Better if you want RJ45 instead of industrial IX plugs. |

### FORECR DSBOARD-THRMAX (Estonia)

| | |
|---|---|
| Size | **140 × 125 mm** |
| Compat | **T4000 and T5000** |
| Price | **€999** carrier-only (~US$1,100) at [forecr.io](https://www.forecr.io/products/nvidia-jetson-thor-carrier-board-dsboard-thrmax). SOM/SSD variants listed **sold out** |
| I/O | 1× GbE RJ45, **QSFP28 4×25G**, 2× HDMI **2.1 out**, USB-C locking, CSI expansion (6×2-lane or 4×4-lane), M.2 NVMe, 18–36 V |
| Camera add-ons | Optional GMSL2 / MIPI cards |
| Notes | Cheapest T4000-capable carrier with a public price. **HDMI is output, not capture.** QSFP matches our uplink story. CAN-FD pins are dead on T4000 (no CAN on the SOM). Made in Europe. |

### Auvidea X242

| | |
|---|---|
| Compat | Published as **T5000**. Dual 10GbE, PCIe x16, 16-lane CSI (NVIDIA P3762 cam) |
| Price | Quote (Auvidea / distributors). Historically cheaper BSP than CTI, more DIY |
| Notes | Don’t assume T4000 until Auvidea says so. CSI-native, no SDI. |

### “Breakout board” in the CTI sense

CTI’s old **XBG*** boards were TX2-era mezzanine breakouts, not Thor. For Thor, the prototype without a custom PCB is: **carrier + camera add-on**, not a pin header fan-out of the 699-pin SOM. Don’t look for a $50 Thor “breakout.”

---

## 2. Getting Blackmagic video *into* Thor

| Widget | Price | What it actually does | 4K? |
|---|---|---|---|
| **CTI JCB003** SDI→CSI | **$1,538** [WDL, in stock](https://www.wdlsystems.com/connect-tech-jcb003-01) | 2× **3G-SDI** in → MIPI. Needs Gauntlet or Rogue-T5 | **No.** 1080p60 max. PYXIS 12G-SDI will not give you 4K through this |
| **CTI JCB010** HDMI→CSI | Quote (JCB010). Page still says Rogue/Forge **Orin/Xavier** — confirm Thor BSP | 4× HDMI → MIPI (Toshiba TC358840) | 4K30 *if* the bridge and BSP allow it. Not confirmed on Thor in public docs |
| USB HDMI capture | $30–200 | UVC into Thor USB | 4K maybe, latency and CPU. Fine for AD, not for “the take” |
| PYXIS USB-C / 1G Ethernet | included | Control, proxy, SSD record. 12K model has **10GbE** | Not a live CSI pipe |
| Open the camera | your time | Sensor is a Sony IMX on a BMD board, not a Jetson CSI pinout | Research project |

**Live 4K from PYXIS into Thor ISP is not a catalog part today.** Plan on: BMD records the master; Thor takes HDMI 1080p/4K from a Pocket or a converter for live AI.

---

## 3. Blackmagic cameras (body)

Street from B&H 2026-09-01 unless noted. All record BRAW internally. None are CSI cameras.

| Camera | Street | Mount / metadata | Video out | Form | Why / why not |
|---|---|---|---|---|---|
| **PYXIS 6K PL** | **$3,675** | **Cooke /i pins at 12 o’clock** (Canon/Cooke/Fujinon/Leica/Zeiss /i lenses). PL not user-swappable | **12G-SDI**, USB-C, **1G Ethernet**, TC/ref | Box, side plates, mounts on a Thor box | **Best match** to LENS.md. /i is real (PYXIS manual). SDI is 4K60 monitoring, not a Thor CSI input |
| **PYXIS 6K EF** | **$3,455** | Active EF (focal/iris/focus). Not /i | 12G-SDI, USB-C, Ethernet | Box | Cheaper glass. Metadata is EF-class, not entrance-pupil /i |
| **PYXIS 6K L** | **$3,465** | L-mount electronic | 12G-SDI, USB-C, Ethernet | Box | Adapt EF/PL *out* (flange). No native /i |
| **Cinema Camera 6K L** | **$2,989** (used ~$2,390) | L-mount electronic, OLP | **HDMI**, USB-C. No SDI | Handheld brick | Cheapest full-frame 6K. HDMI into a capture card is simpler than 12G. Worse “bolted to Thor” |
| **Pocket 6K G2** | **$2,269** (used ~$1,770) | Active EF | HDMI only | Pocket | Cheap Super35. HDMI. No ND. Fine as a sacrificial HDMI source |
| **Pocket 6K Pro** | **$2,835** (used ~$1,820) | Active EF, built-in ND, dual XLR | HDMI | Pocket | Same as G2 plus ND/XLR. Still HDMI |
| **Pocket 4K** | **$1,139** (used ~$930) | MFT electronic | HDMI | Pocket | Too small a sensor for “the” A-cam. OK as an HDMI test mule |
| **PYXIS 12K L/EF/PL** | **$5,825–5,829** | L electronic; PL has /i. **10GbE** | 12G-SDI, 10G RJ45 | Box | Overkill. Early 12K had a sensor-board recall (pre s/n 14221337) |
| **URSA Cine 12K LF** | **$8,435–17,435** | EF/PL | SDI / optional 100GbE | Shoulder | Wrong size/price for a Thor-mounted body |

Blackmagic list prices on their site (PYXIS 6K ~$3,455–3,515) match B&H. Holiday 2025 discounts are over.

### Cracking one open

Teardowns show a sensor board + I/O board + fan. The MIPI from the IMX does not land on a Jetson-compatible connector. /i lives on the PL mount PCB (four pins, RS-232-ish, milliamps — **not** servo power). If you crack a PYXIS PL, the useful steal is the **mount + /i reader**, not the sensor.

Rewire value: tap /i UART and HDMI/SDI. Leave the sensor in the BMD box unless you want a six-week FPGA job.

---

## 4. Suggested carts (pick one)

### Cart S — software this week (no T4000 SOM yet)

1. AGX Thor Dev Kit — **$3,499** Arrow  
2. Pocket 6K G2 — **$2,269** B&H (HDMI mule + EF metadata)  
3. HDMI cable + cheap USB capture if the kit USB stack is easier than CSI  

**~$5.8k.** Matches the resin shell. Not production T4000.

### Cart T — T4000 + Rogue-T5 **(preferred production stack)**

1. T4000 SOM — **$2,749** Arrow `900-13834-0000-000`  
2. **CTI Rogue-T5 AGX302** — quote `sales@connecttech.com` (carrier-only). WDL T5000 assemblies $8.2k+ if you want them to solder a T5000  
3. ATS Thor HS — passive `ATS-NVP-3739` **~$56** (needs system air) or active `ATS-NVA-3740` **~$125** Digi-Key. Prefer measuring the passive on the bench; production wants heatpipes to a radiator, not this brick as the product lid  
4. **PYXIS 6K PL** — **$3,675** B&H (hero /i + BRAW; not the CSI body)  
5. 1–2× RV1126/B IMX415 **PoE turrets** — **$50–150** each (encode mule)  
6. 1× RV1126B EVB/core — **$160–244** (sat software; UART for ToF + /i)  

Carrier + SOM + HS is the T4000 prototype. Live AI is HDMI/USB until a CSI/GMSL add-on. Master is BRAW + /i on the PYXIS until the CSI body exists. Thor remuxes sat HEVC.

FORECR THRMAX (€999, 140×125, QSFP) is the fallback if CTI quotes slowly. Bigger board.

If you need SDI→CSI on day one, add **JCB003 ($1,538)** and accept **1080p** into the ISP.

### Cart C — cine body that is actually /i, Thor is the brain

Same as T, PYXIS PL non-negotiable. Do not buy EF “and add /i later” — the mount is not swappable.

---

## 5. What I would not buy yet

- Auvidea X242 until T4000 is in writing  
- JCB003 as a “4K pipeline” — it is 3G  
- PYXIS 12K (money, recall, 10GbE you don’t need)  
- Integrated CTI T5000 assemblies at $8k+ unless you want them to solder the SOM  
- Opening a Pocket to harvest CSI — wrong pinout  

---

## Contacts

- Arrow T4000 / AGX kit: arrow.com (you already have the DS)  
- Connect Tech: sales@connecttech.com · WDL Systems US reseller  
- FORECR: sales@forecr.io  
- Blackmagic: B&H, or blackmagicdesign.com reseller finder  

## Sources (primary)

- Arrow T4000 `900-13834-0000-000` $2,749 (2026-09-01)  
- NVIDIA / VideoCardz Jul 2026 list-price hike (kit $5,499, T4000 1KU $2,999)  
- FORECR product page €999  
- WDL Rogue-T5 assemblies $8,225+; JCB003 $1,538  
- B&H BMD prices 2026-09-01  
- PYXIS manual: Cooke /i on PL models only  
- CTI JCB003: 3G-SDI, 1080p60, MIPI 8-bit

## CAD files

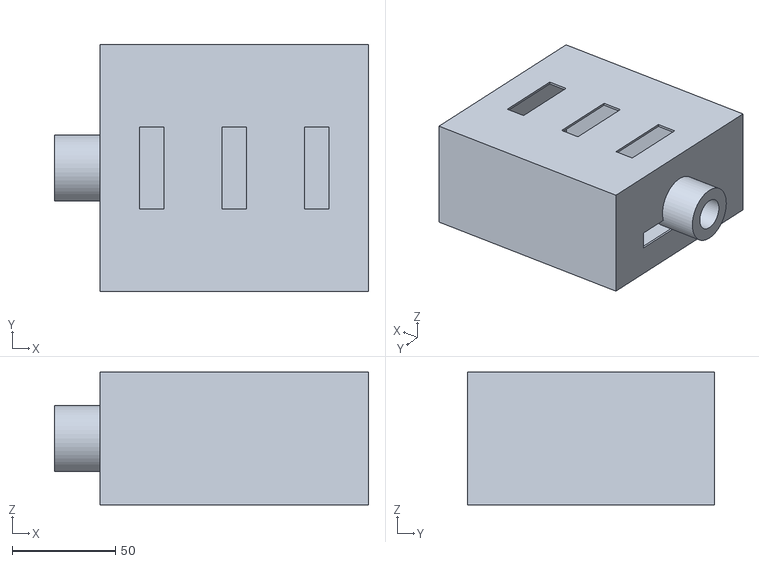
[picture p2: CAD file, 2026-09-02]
docs/cad/agx_shell_front.stl
152.3 x 119.8 x 64.3

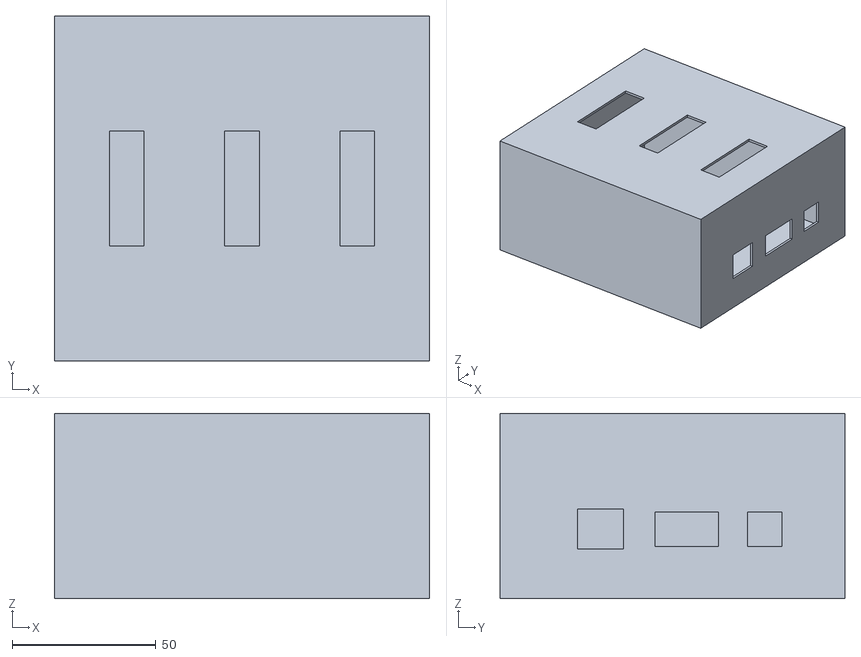
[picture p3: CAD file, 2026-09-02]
docs/cad/agx_shell_rear.stl
130.3 x 119.8 x 64.3

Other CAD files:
docs/cad/agx_thor_shell.blend

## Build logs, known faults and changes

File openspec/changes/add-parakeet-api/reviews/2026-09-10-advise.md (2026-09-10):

# Advise: add-parakeet-api

> **ADVISE:** send-back
> **READER:** agt-fable-5-1-arch-review
> **SPAWN:** /Users/dukejones/work/ClientProjects/AllSystemsGo/AICamera/.spawns/aicam-parakeet-shape-1789079544-12885-077901a4

Rigor: architecture. Density: standard. Reader family: Claude (Fable 5.1). Author family: grok.
Read order: packet Why → change spec `specs/parakeet-asr/spec.md` → `package.json` (adapter-static) →
`sim/3090/serve.py` (bind_ip, port 8745) → daBOM `src/lib/server/api/root.ts` (well-known trio) →
daBOM `src/lib/server/api/app.ts` (`app.doc31`) → Papyrus `morphist-asr/src/runtime/backend.rs`
(`recommend_for_asr`). Blind take written before `proposal.md`, `steer.md`, `design.md`, `tasks.md`
were opened. No living `parakeet-asr` spec exists; capability is ADDED at fold.

## Blind take (written before design.md)

1. **Pin.** The OpenAPI document SHALL carry `servers` with the `/api/v1` base. daBOM's well-known route is `api.request('/openapi.json')`, so the bytes are identical, but an agent that reads `/.well-known/openapi.json` and sees `paths./transcribe` with no `servers` will POST to `/transcribe` at root and get 404. Same bytes is necessary, not sufficient; the document must be self-locating.
2. **Pin.** Sidecar boundary. Bun does not run Parakeet TDT decode natively; the warm engine is a second process (Python + onnxruntime CPU or sherpa-onnx). The spec must say the sidecar listens on loopback or a unix socket only, and that the Bun process is the sole tailnet listener. Otherwise "Tailscale bind" is true of one process and a second unguarded port appears on the same box.
3. **Pin.** CPU-only must be mechanical, not aspirational: `CUDA_VISIBLE_DEVICES=` (empty) in the unit env, the CPU `onnxruntime` wheel not `onnxruntime-gpu`, and provider list hard-set to `CPUExecutionProvider`. Papyrus `recommend_for_asr` classes the 14600KF (Raptor Lake, AVX2+FMA, no AVX-512) as `Avx2Fma` → CPU; the decision here is already made, so cite the rule and pin the env, do not port the detector.
4. **Pin.** CPU contention is the real cost, not VRAM. The 14600KF is 6P+8E and the same box runs the 30 fps compositor's host-side work. A Parakeet session with default intra-op threads takes every core. The spec needs a thread ceiling (intra-op threads ≤ N, e.g. 4) and a scenario: transcribe while the 30 fps plugins run and frame time does not regress. "3090 stays free" without a CPU budget just moves the stall.
5. **Pin.** Weights are a unit artifact, not a first-request download. Pin the INT8 ONNX bundle path (sherpa-onnx `parakeet-tdt-0.6b-v3-int8` or NeMo export) and a checksum in the unit; the "warm sidecar serves the second call" scenario is meaningless if the first call is a multi-hundred-MB fetch.
6. **Pin.** Stream operation shape. `@hono/zod-openapi` `createRoute` can declare `application/octet-stream` request + `application/x-ndjson` or `text/event-stream` response, but not both response types on one operation. Pick one (NDJSON: symmetric with the PCM request, no browser SSE constraints). State that v1 stream clients are non-browser (curl, Bun, Node): streaming request bodies over fetch need HTTP/2 + `duplex: 'half'` which browsers do not do. End-of-stream is connection close; the last event carries `final: true`.
7. **Pin.** Probe. 503 on sidecar-unavailable is stated but unobservable before a clip is posted. Add `GET /api/v1/health` in the OpenAPI document reporting sidecar `warm | cold | down`, provider (`CPUExecutionProvider`), and model id, so the 503 scenario and the CPU-only scenario both have a cheap check.
8. **Refuse.** Any Hono/zod dependency in the root `package.json`. The Pages build is `vite build` with adapter-static; the API must live in its own directory with its own `package.json` and lockfile so the static site's dependency graph does not grow a server. Root already shows `bun.lock` untracked and `package-lock.json` deleted; do not let this change be the reason hono lands at root.
9. **Refuse.** Resampling or channel-mixing in v1. Wrong shape is 422, full stop. The moment the API resamples 44.1k stereo "to be helpful", the 422 scenario is dead and the CPU budget in (4) is unknowable. WAV with a non-audio content-type is 415, not 422.
10. **Tradeoff.** Python sidecar vs Bun-native ONNX (`onnxruntime-node`). Bun-native is one process and no protocol, but TDT greedy decode + SentencePiece tokenizer must be re-implemented and maintained. Python (sherpa-onnx) is the supported Parakeet path today, costs a second process and a loopback protocol, and is what Papyrus deliberately did not do because it is Rust-native. Take the sidecar: the Bun process is the contract, the engine is swappable, and the "do not vendor" constraint stays honest.

## Compare against proposal.md, steer.md, design.md, tasks.md

Also read after the take: sibling changes `add-parakeet-engine`, `add-parakeet-hono`,
`add-parakeet-stream` (all ADD to `parakeet-asr`), daBOM `app.ts:657` (`servers: [{ url: '/api/v1' }]`).

**Shape matches the take.** Standalone Bun + Hono + `@hono/zod-openapi` on fractal1, `:8750`
beside bay-feed `:8745`, Tailscale IPv4 only, daBOM well-known trio, warm Python `onnx-asr` INT8
sidecar, CPU EP with `CUDA_VISIBLE_DEVICES=` and four intra-op threads, windowed TDT for stream,
no vendoring of morphist-asr. The steer decided the same five things the take would have decided.
This change is the shape node; engine, hono, and stream do the writes, so a three-line `tasks.md`
is correct, not thin.

**Answered by the author** (take → where):
- (2) sidecar boundary → design: `--stdin/IPC-->`; no second port. Correct choice.
- (3) mechanical CPU-only → design: `CUDA_VISIBLE_DEVICES=` + `providers=["CPUExecutionProvider"]`.
- (4) thread ceiling → design: "Four intra-op threads." Engine proposal repeats it.
- (5) weights as artifact → engine tasks: `~/aicam/parakeet-cpu` INT8 weights on fractal1.
- (8) not in root `package.json` → engine tasks: `asr/` or `sim/parakeet/`. Directory undecided but off-root.
- (10) sidecar over Bun-native → steer: Python `onnx-asr` sidecar, decided.

**Not answered, and each is a line in the spec that gets folded living.** `design.md` and
`tasks.md` do not fold; `specs/parakeet-asr/spec.md` does. Four of the author's good answers live
only in design, and one design line contradicts the spec.

1. **Design contradicts spec on resampling.** Spec, Clip transcribe: "Wrong sample shape SHALL be
   422." Design, Audio: "Other rates resample in the sidecar or 422." The engine actor reads design.
   If the sidecar resamples, the 422 scenario is dead and the four-thread budget is unknowable.
   Strike "resample in the sidecar or" from design. Spec wins; say so.
2. **Health is promised in the journey and absent from the spec.** Proposal, Empty: "model not
   loaded yet. Health says so; transcribe is 503, not a hang." No requirement produces a health
   operation. Without it the 503 scenario is only observable by posting audio. Add
   `GET /api/v1/health` to the Well-known or Clip requirement: reports sidecar `warm|cold|down`,
   provider, model id, and is listed in the document.
3. **Sidecar listener is undecided across the DAG.** Design says stdin/IPC. Engine tasks say
   "systemd unit Tailscale-adjacent to bay-feed, **or** stdin protocol the Bun process owns."
   Tailscale-adjacent means a second tailnet port that the Tailscale-bind requirement does not
   cover (it names "the ASR process", singular). One sentence under Tailscale bind: the sidecar
   SHALL NOT open a network listener; it is a child of the Bun process on stdin/IPC. That closes
   the engine "or" from the spec that owns the boundary.
4. **Thread ceiling and no-CUDA env are design-only.** CPU-only Parakeet requirement says
   `CPUExecutionProvider` and "SHALL NOT create a CUDA context" but not how. Add: the sidecar
   SHALL run with `CUDA_VISIBLE_DEVICES` empty and intra-op threads ≤ 4. The GPU scenario is
   already good; add one CPU scenario: transcribe while bay-feed's 30 fps stack runs, frame time
   does not regress. That is the actual cost on this box, and the spec is silent on it.
5. **`servers` is the difference between "same bytes" and "self-locating".** daBOM sets
   `servers: [{ url: '/api/v1' }]`; "copy daBOM" implies it, but the hono sibling's scenario
   accepts "`/transcribe` or `/api/v1/transcribe` as declared", which is exactly the ambiguity an
   agent trips on. Well-known requirement: the document SHALL carry `servers` with the `/api/v1`
   base so `paths` keys are relative to it. One line.

**Notes, not blocking.**
- NDJSON or SSE: spec, design, steer, and stream sibling all say "NDJSON/SSE". Recommend NDJSON:
  symmetric with the PCM request, no SSE framing, and browser SSE ergonomics do not matter because
  streaming request bodies over fetch need HTTP/2 + `duplex: 'half'` that browsers do not do.
  State v1 stream clients are non-browser. If the author keeps "as declared" that is acceptable;
  the document is the contract.
- Four changes ADD to one new capability. This change carries the full spec; engine, hono, stream
  carry narrower requirements that overlap it (engine "Warm CPU sidecar" ⊂ api "CPU-only" +
  "Clip transcribe"). Fold this change first and fold the siblings as scenarios under its
  requirements, not as parallel requirements, or the living spec says the same thing three ways.
- Hardcoded default `100.103.147.70` in the spec is fine as a default; the unit should resolve
  like `serve.py` `bind_ip()` (env → `tailscale ip -4` → default) and never fall through to
  `0.0.0.0`. Design already says never `0.0.0.0`.
- WAV with a non-audio content-type is 415, not 422. Reserve 422 for declared-but-wrong shape.

**Verdict.** Send-back. The architecture is right and every decision in the steer holds. The
send-back is five spec lines and one struck design clause, so the living spec carries what the
design already knows. Re-advise should be short.

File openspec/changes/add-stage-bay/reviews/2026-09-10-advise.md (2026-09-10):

# Advise: add-stage-bay

> **ADVISE:** accept
> **READER:** agt-fable-5-1-arch-review
> **SPAWN:** /Users/dukejones/work/ClientProjects/AllSystemsGo/AICamera/.spawns/add-stage-bay-1789034625-41352-80c40a60

Rigor: architecture. Density: lean. Reader family: Claude (Fable 5.1). Author family: grok.
Read order: packet Why → `openspec/specs/hardware-kit/spec.md` (empty) → change spec →
`sim/3090/serve.py`, `sim/3090/snapshot.py`, `vite.config.ts`, `src/routes/bay/+page.svelte`,
`src/lib/bay/*`, `src/routes/+layout.svelte`, `src/routes/layout.css`, `docs/3090-SIM.md`.
Blind take written before `design.md` / `tasks.md` / `proposal.md` / `steer.md` / `notes/` were opened.

## Blind take (written before design.md)

1. **Pin.** The Tailscale IP `100.103.147.70` is hardcoded in two files (`serve.py` BIND, `vite.config.ts` proxy target). One constant, or resolve it: `tailscale ip -4` at serve start, MagicDNS `fractal1` in the proxy.
2. **Pin.** Derates are declared owned by `docs/3090-SIM.md`, yet `snapshot.py` hardcodes `filter_k 0.13 / bandwidth_k 0.30` and bakes them into the plate. The doc itself says ×0.29 in the summary and ×~0.30 in the table. Three copies, two values.
3. **Pin.** Per-mag `RESIDENT` is process-granular, not model-granular: any `python.*(pipeline|diffusers|transformers|sam2)` process marks SAM2 and CLIP resident, and klein too. Running SAM2 alone lights all three. The spec scenario only tests idle, so this passes the spec while lying under load.
4. **Pin.** `cap 420` is a string literal on the glass. The sim doc says the 3090 is a 350 W card. `power.limit` is one more field on the existing `nvidia-smi --query-gpu`.
5. **Pin.** Plate age lives only in the footer. On Pages the slate still says `HOLD` with a tally, which reads as live-idle. Plate date belongs beside `PLATE` in the slate. And there is no one-line plate refresh; the plate will rot.
6. **Refuse.** Any feed bind other than the Tailscale address. Refuse `0.0.0.0`. Refuse a public tunnel or relay to make Pages "live"; mixed content (https Pages → http 100.x) blocks it anyway, and the honest answer is the plate.
7. **Refuse.** Treating `vite dev` as the only live surface forever without saying so. A tailnet-served build (`vite preview`, any static host on 100.x) will never go live because the fetch is `import.meta.env.DEV`-gated. Acceptable now; it must be written down.
8. **Tradeoff.** DEV gate vs hostname gate. DEV gate is one line, zero console noise on Pages, and cannot leak a 100.x fetch into a public build. Hostname gate would let a tailnet-hosted build go live but reopens CORS (`Access-Control-Allow-Origin: *` is already on the feed) and mixed-content questions. Take DEV; revisit only if a tailnet static host appears.
9. **Concern.** Tactic Sans (Reg, ExtExd Black) and Space Age are committed as font binaries in a public Pages repo. No license file beside them. Web-embedding rights for Tactic Sans need checking before this is public.
10. **Concern.** Fold target. The living spec cited is `hardware-kit`, the change delta is `specs/stage-bay/`. `openspec/specs/stage-bay/` does not exist. The fold must create it, or the delta silently goes nowhere. Also `+layout.svelte` locks on `pathname.includes('/bay')`; no collision today, but `startsWith(base + '/bay')` is the intent.

## Compare against design.md, proposal.md, steer.md, tasks.md

**Architecture matches the take.** Design names the exact reason for the split: Pages is HTTPS, fractal1 is HTTP on 100.x, mixed content blocks it. Steer records it as decided. The feed is Tailscale-bound and the design gives the stronger reason I did not have: **UPnP is on**, so `0.0.0.0` could be punched through the router. Refusal 6 is answered and strengthened. Accept the data plane as designed.

**Design claims the glass does not own derates. Code disagrees.** Design: "Derate constants stay in `docs/3090-SIM.md` — the glass cites them, it does not own them." The self-critique repeats it. But `snapshot.py` emits `t4000_read` with its own literals and the plate carries them. The glass does not own them; the *feed* does, which is the same problem one hop away. Pin 2 stands. Fix is small: either the feed stops emitting `t4000_read` and the page imports the numbers from the doc frontmatter at build time, or the doc frontmatter becomes the single source the snapshot reads. Also reconcile 0.29 vs 0.30 in the doc.

**Proposal journey promises a "BRICK DARK" slate. Code has no such state.** Journey row "Failed / brick dark: fetch timeout. Last plate with a 'BRICK DARK' slate." In `+page.svelte` a failed pull sets `live: false` and the slate reads `PLATE`, indistinguishable from the Pages case where no fetch was ever attempted. The Why says the data plane "has to be honest about live vs plate"; there are three states (live, tried-and-dark, never-tried) and the glass shows two. Pin 5 sharpens into this: add a `dark` flag, show `BRICK DARK` in DEV on failure, `PLATE` plus date on Pages.

**Residency (pin 3).** Design says "stack catalog with `resident`" and nothing about granularity. Not contradicted, just unaddressed. The author must answer it: either the glass says one thing ("AI PROCESS ON TUBE") or `pipeline.py` writes a per-model manifest the snapshot reads. Not a send-back; the spec scenario as written is met.

**tasks.md** checks "JSON contract in `stage-bay` spec". The spec has no JSON contract; `src/lib/bay/types.ts` is the contract. Fine, but the checkbox overstates. Tasks are otherwise thin for a landed change: no plate-refresh step, no font-license step, no fold-target step.

**Steelman for the author.** This is a one-person lab EVF, landed on `main` in one commit, whose only live consumer is a Mac on the tailnet running `vite dev`. Hardcoded IP, hardcoded cap, and process-level residency are all correct *today* on this one brick. Adding a manifest protocol for residency before the pipeline even runs three models at once would be spec-first waste. I agree, which is why this is accept-with-pins and not send-back: the architecture is right and each pin is a local edit, not a redesign.

## Why accept, not send-back

Send-back is for a design that contradicts the spec or a data plane that needs redoing. Neither applies. The live-vs-plate split, the Tailscale-only bind, the DEV gate, and the dark lock all hold up against the cited code. The gaps are one design sentence the code does not yet honor (derate ownership), one journey state the glass does not yet render (BRICK DARK), and housekeeping (plate refresh, fold target, fonts). Pinned as unchecked tasks below; none blocks act on the next node.

## Pinned to tasks.md

Appended as unchecked items. See `tasks.md`.

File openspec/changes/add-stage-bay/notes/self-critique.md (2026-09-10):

# Self-critique (author tab — not advise)

Author family: grok. Do not treat this as ADVISE.

- Mixed-content call is the load-bearing one. Vite proxy is same-origin; Pages is plate. Correct.
- Feed bind is Tailscale-only; curl 127.0.0.1:8745 fails on purpose.
- Glass cites 3090-SIM derates, does not own them.
- Residual: other-family advise still owed on this architecture change.

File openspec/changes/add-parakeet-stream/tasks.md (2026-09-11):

# Tasks

- [x] Stream route on the Hono app (chunked POST or WS; one, named in OpenAPI)
- [x] Windowed TDT decode on the sidecar
- [x] NDJSON or SSE events `{text, t0, t1}`
- [x] Well-known spec lists the stream operation
- [ ] GPU idle during a 30 s pipe

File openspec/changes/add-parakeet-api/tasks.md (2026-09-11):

# Tasks

- [ ] Living spec `parakeet-asr` with well-known discovery, CPU engine, Tailscale bind, clip + stream
- [ ] `ARCHITECTURE.md` note: Bun ASR process beside Pages SSG (owed at fold; draft in design.md)
- [x] Advise accept before engine/hono writes
- [x] Advise send-back 2026-09-10: strike resample; health op; sidecar no-listener; CUDA_VISIBLE_DEVICES + ≤4 threads + CPU scenario; servers `/api/v1`; NDJSON stream
- [x] Re-advise 2026-09-10: accept (`reviews/2026-09-10-re-advise.md`); notes to hono/stream nodes, none blocking

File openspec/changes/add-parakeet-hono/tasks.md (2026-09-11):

# Tasks

- [x] Bun workspace `asr/server/` with Hono + `@hono/zod-openapi` + Zod routes
- [x] `app.doc31('/openapi.json')`; root serves `/.well-known/openapi.json` as the same bytes
- [x] RFC 9727 `/.well-known/api-catalog`
- [x] `POST /api/v1/transcribe` wired to the warm sidecar
- [x] Bind Tailscale IPv4 `:8750` only
- [x] `bun test` via `app.request` for spec equality + transcribe 422/503 shapes

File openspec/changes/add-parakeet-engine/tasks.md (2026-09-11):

# Tasks

- [x] Sidecar under `asr/engine/` using fractal1 `~/aicam/parakeet-cpu` INT8 weights
- [x] Force CPU: `CUDA_VISIBLE_DEVICES=` and `providers=["CPUExecutionProvider"]`
- [x] Keep process warm; second transcribe does not re-download / re-load encoder
- [x] Sidecar is a Bun child on stdin/IPC — no TCP/UDP listener
- [ ] Smoke: `2086-149220-0033.wav`; nvidia-smi memory.used unchanged (fractal1, after deploy)

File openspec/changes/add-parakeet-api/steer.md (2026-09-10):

# steer add-parakeet-api

**When.** 2026-09-10
**Depth.** standard

## Decided
- Discovery: `/.well-known/openapi.json` + `/.well-known/api-catalog` (user). Same bytes as `/api/v1/openapi.json`. daBOM shape on this repo's Bun process.
- Engine: warm Python onnx-asr INT8 sidecar on fractal1 (decide-for-me / intend recommended). Do not vendor morphist-asr.
- Bind: Tailscale-only, port 8750, never `0.0.0.0` (decide-for-me).
- Stream: windowed TDT, PCM in, NDJSON/SSE text out (decide-for-me). Unified partials later.
- Runtime: standalone Bun + Hono + `@hono/zod-openapi` (decide-for-me). Not SvelteKit, not daBOM `hooks.server.ts`.
- Activate all four DAG nodes (user).

## Skipped
- none

## Feeds change
Publish the generated OpenAPI 3.1 document at a well-known URL so any
agent can discover transcribe and stream without reading the notebook.
CPU-only Parakeet beside the Pages app; GPU stays on 30 fps plugins.

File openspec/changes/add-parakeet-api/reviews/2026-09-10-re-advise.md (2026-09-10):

# Re-advise: add-parakeet-api

> **ADVISE:** accept
> **READER:** agt-fable-5-1-arch-review
> **SPAWN:** /Users/dukejones/work/ClientProjects/AllSystemsGo/AICamera/.spawns/aicam-parakeet-shape-1789079938-41901-4c435cab

Rigor: architecture. Density: standard. Reader family: Claude (Fable 5.1). Author family: grok.
Prior: `reviews/2026-09-10-advise.md` (send-back, five spec lines + one struck design clause).
Amend under review: `4194d0f`.
Read order: packet Why → `proposal.md` → `steer.md` → change spec `specs/parakeet-asr/spec.md` →
prior review → daBOM `src/lib/server/api/app.ts:657` (`servers: [{ url: '/api/v1' }]`) and
`root.ts:30-37` (well-known trio). Blind take written before `design.md`, `tasks.md`, and the
sibling deltas were opened. No living `parakeet-asr` spec exists; capability is ADDED at fold.

## Blind take (written before design.md / tasks.md)

1. **Pin, held.** `servers` `/api/v1` is now a SHALL in Well-known, and the first scenario checks it. The document is self-locating. This was the one line that turned "same bytes" into a contract; it is there.
2. **Pin, held.** Sidecar has no network listener; Bun is the sole tailnet socket; the `sidecar has no port` scenario is `ss`/`lsof`-checkable. The Tailscale-bind requirement now covers both processes, not "the ASR process" singular.
3. **Pin, held.** CPU-only is mechanical: `CUDA_VISIBLE_DEVICES` empty, `CPUExecutionProvider`, intra-op ≤ 4, and a scenario that runs a clip beside the 30 fps stack. The cost on this box is the CPU steal, and the spec now names it.
4. **Pin, held.** `GET /api/v1/health` reports `warm | cold | down`, provider, model id, and is listed in the document. The 503 and the GPU-idle scenarios both have a cheap probe.
5. **Pin, held.** Stream is NDJSON `{text, t0, t1, final}`, non-browser v1, listed in the document, last event `final: true`. One response type per operation, as `createRoute` needs.
6. **Refuse, held.** No resample. "Wrong sample shape SHALL be 422" stands alone; the "or resample in the sidecar" escape is gone from the spec. Must confirm it is also struck from design, since the engine actor reads design.
7. **Refuse, held.** 415 for non-audio content-type, 422 for declared-but-wrong shape. The two are separated as asked.
8. **Would pin, minor.** Health SHOULD answer 200 in every sidecar state with the state in the body. A `/health` that returns 503 when the sidecar is cold is indistinguishable from Bun being down, which is the one thing the probe exists to separate. The spec does not say the status code; the hono actor will pick one. One clause.
9. **Would refine, minor, my own wording.** "End-of-stream is connection close" came from my prior take and the author copied it. If the client closes the TCP connection the server cannot deliver `final: true`. The precise statement is: end-of-input is end of the request body (half-close); the server then emits the last event with `final: true` and closes the response. This is a stream-sibling implementation detail; the intent is unambiguous.
10. **Tradeoff, accepted.** Raw PCM on `POST /transcribe` needs a declared content-type so the 415 rule is clean; `audio/L16; rate=16000; channels=1` (RFC 2586) or `application/octet-stream` named in the document. "As declared in the spec" delegates this to the OpenAPI document, which is the contract. Fine, the document decides, not prose.

## Compare against design.md, tasks.md, sibling deltas

Opened after the take: `design.md`, `tasks.md`, `add-parakeet-{engine,hono,stream}` spec deltas
and tasks, `sim/3090/serve.py` `bind_ip()` (env → `tailscale ip -4` → `100.103.147.70`).

**Every send-back item landed in the spec, and design agrees with it.**

| Send-back item | Spec (folds) | Design (does not fold) |
|---|---|---|
| 1. Resample contradiction | "Wrong sample shape SHALL be 422", no escape | "The sidecar does not resample or mix channels." Struck. |
| 2. Health op | Clip transcribe: `GET /api/v1/health` `warm\|cold\|down`, provider, model id, listed | Not repeated; not needed. |
| 3. Sidecar listener | Tailscale bind: "SHALL NOT open a network listener ... child on stdin/IPC. Bun SHALL be the sole tailnet socket" + `sidecar has no port` scenario | Same sentence. Engine tasks: "Bun child on stdin/IPC — no TCP/UDP listener". The "Tailscale-adjacent unit **or**" is gone. |
| 4. CPU env + threads + CPU scenario | CPU-only: `CUDA_VISIBLE_DEVICES` empty, intra-op ≤ 4, `transcribe beside 30 fps plugins` scenario | `CUDA_VISIBLE_DEVICES=`, `providers=["CPUExecutionProvider"]`, four threads. |
| 5. `servers` | Well-known: "SHALL set `servers` to the `/api/v1` base"; scenario checks it | Table row: `servers: [{ url: '/api/v1' }]`. Matches daBOM `app.ts:657`. |
| note: NDJSON | Audio stream pipe: NDJSON `{text, t0, t1, final}`, `final: true` last, non-browser v1 | NDJSON only; "v1 stream clients are non-browser". |
| note: 415 vs 422 | Both codes, separated | Both codes, separated. |

The hono sibling's scenario that accepted "`/transcribe` or `/api/v1/transcribe` as declared" now
reads "`servers` includes `/api/v1`, and `paths` includes `/transcribe` and `/health`". The
ambiguity the take was about is closed across the DAG, not just in this change.

Steelman against the take: the take's remaining items (8, 9, 10) are each one clause an
implementer can get right from the spec's intent, and none of them is a line that would fold
wrong. Item 8 (health status code) is the strongest; a `/health` that 503s when cold does not
break any stated scenario, it only weakens the probe. That is a hono-node test, not a shape
send-back. Item 9 is my own phrase; the author should not be sent back for copying the reader.
Item 10 is delegated to the OpenAPI document by design, which is the point of the change.

**Notes, not blocking. Addressed to the sibling actors and the folder.**

- **Health status code (hono).** `GET /api/v1/health` SHOULD return 200 in every sidecar state
  with the state in the body. Reserve 503 for `/transcribe`. Otherwise "sidecar cold" and "Bun
  down" look the same to a probe. Worth one clause at fold under Clip transcribe.
- **Half-close, not connection close (stream).** Read "end-of-stream is connection close" as: the
  client ends the request body; the server emits the last event with `final: true`, then closes
  the response. If the client tears down TCP first, no `final` can arrive and that is the
  client's fault, not a failed scenario. Stream tasks still say "NDJSON or SSE `{text, t0, t1}`"
  and "chunked POST or WS"; the shape spec has decided both. NDJSON with `final`, and chunked
  POST, because OpenAPI 3.1 cannot describe a WebSocket and the spec says the stream operation
  SHALL appear in the well-known document. WS is refused by the shape spec, not by this note.
- **Workspace vs own lockfile (hono).** Hono tasks say "Bun workspace `asr/`". A root
  `workspaces` entry shares the root `bun.lock` with the Pages build, which is the graph the
  prior take refused to grow. Prefer `asr/` with its own `package.json` and lockfile, no root
  workspace membership. The spec line "SHALL NOT be mounted inside the SvelteKit adapter-static
  app" is satisfied either way; this is about the lockfile, not the mount.
- **Raw PCM content-type (hono).** Declare it in the document (`audio/L16; rate=16000; channels=1`
  or `application/octet-stream`) so the 415 rule has a clean edge. Prose says "as declared in the
  spec"; the document is where it gets declared.
- **Bind resolution (hono).** Default `100.103.147.70` in the spec is fine; resolve like
  `serve.py` `bind_ip()` (env → `tailscale ip -4` → default) and never fall through to `0.0.0.0`.
  Design already says never `0.0.0.0`.
- **Fold order (folder).** Unchanged from the prior review. This change carries the full
  capability; engine "Warm CPU sidecar", hono "Well-known spec is served", stream "Stream listed
  in well-known" are each a subset of a requirement here. Fold this change first; fold the
  siblings as scenarios under its requirements, not as parallel requirements.
- **`ARCHITECTURE.md`** note is owed at fold per tasks; design.md is the draft. Fine.

**Verdict.** Accept. The five spec lines and the struck design clause from the send-back are all
present, spec and design say the same thing, and the sibling deltas no longer contradict the
shape. Nothing left here folds wrong. Remaining notes are sibling-node implementation clauses.

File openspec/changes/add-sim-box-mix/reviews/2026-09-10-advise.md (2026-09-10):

# advise: add-sim-box-mix (2026-09-10)

> **ADVISE:** accept
> **READER:** agt-fable-5-1-arch-review
> **SPAWN:** .spawns/aicam-sim-box-mix-1789064442-97603-42ec7bd9

## Blind take (written before design.md / tasks.md)

Sources: Why, `openspec/specs/hardware-kit/spec.md`, change delta, `docs/3090-SIM.md`, `HARDWARE.md`, `MODELS.md`, `VIDEO-PERCEPTION.md:100-160`.

1. PIN: 3090 is an emulator, never a 30 fps host. Swap one slot, unload, log the ×0.13 / ×0.30 derates. Correct and already earned by 3090-SIM Measured.
2. PIN: residency (`resident` / `swap`) and pack (`SMALL` / `LARGE`) must be two independent axes in the software, with envelope id only setting the default. The delta welds `6000` → resident+LARGE, but 3090-SIM's own reason to rent the PRO 6000 is the 64 GB co-resident question, which is resident+SMALL. That combination has no home in the delta.
3. REFUSE: any T4000 fps claim derived from a PRO 6000 run. 1792 vs 273 GB/s; 3090-SIM already says the 6000 "will lie high" on TOPS. The delta says both T4000 and 6000 are "the 30 fps path" in one scenario; the 6000 stream is a lab result, not a body result. Needs a derate line (or an explicit "no derate exists; capacity only") for the `6000` envelope the way 3090-SIM has one for the 3090.
4. GAP: the four-box list has no slot for the bring-up brick. Living spec says bring-up SHALL use the AGX Thor Dev Kit (T5000: 128 GB, 2× NVENC, 2560 CUDA). If the dev kit reports as `t4000` its numbers lie high on TPC and NVENC; the envelope id list should say what id the dev kit runs under and whether its fps counts as T4000 FACT.
5. PIN: swap-mode logs must split load/unload time from per-frame time before the derate is applied. 3090-SIM's klein row already conflates ("load + warmup in that"); applying ×0.30 to a number that includes a weight load is noise.
6. NOTE: HARDWARE.md is in `web3d-space` (Family repo), not this repo. Kit table still says T5000 production and 128 GB; living spec says T4000 default. The change must name the cross-repo edit explicitly or the "three boxes" banner stays stale. MODELS.md:7 needs SMALL / LARGE columns, same repo.
7. NOTE: "SAM 3.1 + VDA-L SHALL NOT be packed on T4000 with the AD 9B" is weaker than the source (VIDEO-PERCEPTION: bandwidth, not VRAM, so not together on the body at all). The SMALL pack definition covers it implicitly; make the SHALL NOT unconditional.
8. NOTE: RunPod 6000 Server (600 W passive) and a truck 6000 (likely Max-Q 300 W) share the `6000` cost column "until measured apart". Fine for now; the column header should say which one was measured.
9. TRADEOFF (accepted, must be stated): swap emulation keeps one code path and tests each slot's correctness, but by construction never exercises inter-slot contention on shared bandwidth, which is exactly the T4000 problem. The 6000 tests capacity and lies on bandwidth. No box in the four-box list validates resident-set fps at 273 GB/s except Thor silicon. The change should say so in one line so nobody reads a 6000 30 fps as a body pass.
10. VERDICT-SHAPE: accept if design/tasks answer 2, 3, 4 (independent axes, 6000 derate/no-derate line, dev-kit id). Send-back if the 6000 resident+SMALL run has no home, because that is the stated reason for renting it.

## Compare (after design.md, tasks.md, proposal.md, steer.md)

Steelman first. The design answers most of the take:

- **Take 1 (3090 emulator, never 30 fps host).** Answered. Design envelope row says "Swap one SMALL slot at a time. Slow on purpose." Steer has it as a user decision.
- **Take 2 (residency and pack as independent axes).** Half answered. Design: "Residency is config (`resident` | `swap`). Pack is the envelope id." That is already two axes, and the envelope→pack map is a lookup (`t4000`→SMALL, `3090`→SMALL, `6000`→LARGE), so an override is one row, not a redesign. The delta text disagrees with the design: it says the software selects *both* residency and pack "by envelope id". Steelman: the 64 GB co-resident question in 3090-SIM is 9B + klein + SAM2 (AD and snap profiles), and the design says 9B is NEAR, not a live slot, so that test is outside this change's live mix. Accepted as out of scope. Remaining ask: hardware id (what the log attributes derates to) and pack id (which weights) must not be the same field, or a 6000 running SMALL logs as a T4000 FACT. Task added.
- **Take 3 (6000 fps is not a T4000 claim).** Not answered anywhere in design, proposal, or steer. Steelman: MODELS.md already has "Thor numbers are SPEC unless marked FACT", and the 6000 runs LARGE weights so no derate could apply. But the delta scenario puts "rented PRO 6000 or local T4000 → the 30 fps path" in one THEN clause, and the proposal says "the same software streams realtime" on both. A reader will take a 6000 30 fps stream as the body target met. One line closes it. Task added.
- **Take 4 (bring-up brick has no envelope id).** Not answered. The living spec's Lab brick requirement mandates the AGX Thor Dev Kit (T5000: 128 GB, 2× NVENC, 2560 CUDA, same 273 GB/s). The four-box SHALL enumerates without it, so the first Thor-silicon run has no id to select residency and pack by, and HARDWARE.md's four-box rewrite would drop the T5000 row while the living spec still requires that brick. The delta already has the fix pattern for the two 6000s: "share the column until measured apart." Same sentence for the dev kit, plus the partial derate (bandwidth-bound ~1×, TPC-bound ×0.6, NVENC 2 not 1). Task added. This was the send-back candidate; it does not send back because the delta task in tasks.md is still unchecked, so the delta is finalized during act and can carry the line.
- **Take 5 (swap log splits load from per-frame).** Not answered. 3090-SIM Measured already conflates it on the klein row. Task added; small.
- **Take 6 (cross-repo edits).** Answered. Tasks name web3d-space files explicitly.
- **Take 7 (SAM 3.1 + VDA-L SHALL NOT be conditional on 9B).** Design is stronger than the delta ("Do not squeeze SAM 3.1 + VDA-L + 9B onto the SOM" and the SMALL pack excludes them outright). Delta wording should match design. Folded into the delta task; note only.
- **Take 8 (Server vs Max-Q 6000 sharing a column).** Design says so explicitly. Accepted.
- **Take 9 (no box validates T4000 resident fps at 273 GB/s).** Not stated, but it is the same fact as take 3 from the other side. One line in the delta or 3090-SIM covers both.

Delta-vs-design drift to fix in the delta task: delta says residency is selected by envelope id; design says residency is config. Design is right (a 6000 can run `swap` to reproduce a 3090 result; a 3090 must not run `resident`). Say "default by envelope id, overridable" in the delta.

## Verdict reasoning

The architecture is sound: one code path, named slots, residency and pack as configuration, 3090 as a swap emulator with the derates kept where they already live, cartridge ids that match. Nothing in the take is a competing design. The unanswered items (3, 4, 5, and the hardware-id vs pack-id split from 2) are each one line in the delta or the log format, and the delta is still an open task, so act can carry them. Four tasks appended to `tasks.md`, tagged `advise`. Fold should not proceed with those unchecked.

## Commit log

2026-09-01 chore: init repo, track docs/ only
    Ignore everything except docs/, .gitignore, and AGENTS.md until there is code to land.
2026-09-01 docs: hardware ground, stream budget, and model map
    Cite web3d-space for product docs. Hybrid fabric: body CSI/GMSL, PoE
    satellites. AGX Thor kit is T5000; T4000 is the production encode ceiling
    (HEVC HQ 2× 4Kp30). Bring-up is 1 body + 2 sats at 4K30.
2026-09-02 docs: ingest Arrow Jetson Thor modules DS-11945-001 v1.4
    T4000 extract: 70 W default / 90 W throttle, 1× NVENC HQ 2× 4Kp30,
    3× 25GbE independent (not aggregated 100G), 87 × 100 × 15.29 mm.
2026-09-02 docs: record path is HEVC, not RAW over the wire
    Thor NVENC / camera H.265. CSI RAW is the body-sensor hop into the SoC.
    Bring-up 1+2 4K30 fits in 5GbE; NVENC count is the remaining limit.
2026-09-02 feat: activate hardware-kit changes and land body docs
    Human activated all aicam-kit nodes. OpenSpec ACTIVE BUILD for
    interconnect, carrier, sensors, power, datasheets, enclosure.
    Advise accept-with-nits on the four architecture changes.
    STL still blocked on Blender MCP; print stays human.
2026-09-02 feat: Cooke /i–class lens metadata from every camera
    JSONL sidecar 1:1 with HEVC. Body PL/barrel; sats /i-to-Ethernet.
    P-iris PoE boxes are picture stubs, not hero glass.
2026-09-02 feat: AGX Thor two-part resin enclosure STLs from Blender
    Fit-check shell around the 243 x 112 x 57 mm kit. Front camera boss,
    rear cable cuts, split for a ~192 x 120 mm vat. Manifold.
    [agx_shell_front.stl, agx_shell_rear.stl, agx_thor_shell.blend]
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2026-09-02 docs: shopping brief for T4000 carriers and Blackmagic bodies
    PYXIS 6K PL for Cooke /i. FORECR or Rogue-T5 instead of a custom PCB.
    JCB003 is 3G-SDI (1080p), not 12G.
2026-09-02 docs: CSI vs GMSL and a widened camera list
    Thor speaks CSI. GMSL is a 15 m coax truck that dumps CSI at the
    carrier. Body = CSI; sats = GMSL or PoE; PYXIS stays HDMI/SDI.
2026-09-02 docs: GMSL2 camera count vs PoE H.265 sats, Thor-in-body size
    Honest GMSL2 4K RAW is 4 cameras (8 at 2-lane). Pi is the wrong
    encode SoC; RV1126/RV1126B is the sat. Product shape is T4000
    inside the camera body, not the AGX kit brick.
2026-09-02 feat: SvelteKit SSG notebook on GitHub Pages
    Publish the hardware tree as a static site under StudioWorldTree:
    mdsvex compiles docs/ and openspec/, adapter-static prerenders,
    and GitHub Actions deploys to Pages. Home, kit, and decisions
    summarize locked calls; every markdown file is reachable to drill
    into.
    Also land the T4000 thermal extract (TDG-12271-001 v1.3) that
    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
2026-09-02 docs: turret vs RV1126B module, lidar sidecar, Thor thermal hold
    TDG-12271-001 v1.3 in tree. 70 W fanless cine body is not honest;
    prefer heatpipes/radiators. Rogue-T5 is the carrier. Crack a PoE
    turret as encode mule; ship the module. 1D ToF on every sat, one
    3D lidar on the rig.
2026-09-02 docs: put thermal on the notebook as a hardware chapter
    TDG-12271-001 v1.3 is no longer a buried datasheet. Heat sits next to
    power: 70 W fanless is not honest, cooler is customer-side on the TTP,
    ranked radiator paths, and the kit page carries the θpa numbers.
2026-09-02 Point agents at sister daBOM for the parts crib.
    The GitHub Pages notebook is not the BOM system. SKUs, quotes, and
    BOMs live in ../daBOM (Hono REST + PGLite).
2026-09-03 docs: point at the web3d-space T4000 RunPod sim
    Current box is RTX PRO 4500 Blackwell in EU-RO-1 (lduog58vatxh44).
2026-09-04 feat: hero viewer prefers a GLB, STLs as fallback
    Drop docs/cad/hero.glb and the top orbit canvas uses it. Hover warms
    the Three.js chunk; click still boots WebGL. No file yet, so the two
    print STLs remain the live model.
2026-09-04 feat: Meshy camera GLB in the hero, studio-lit
    Compress the 138 MB Meshy export to a 2.1 MB Draco/WebP web mesh
    (docs/cad/hero.glb). Auto-load at the top with tungsten key, cool rim,
    and on-demand orbit. Falls back to the print STLs if the GLB is missing.
2026-09-04 fix: drop the hero poster still
    The GLB is the top of the page. No more CAD screenshot to keep in sync.
2026-09-04 fix: pull the hero camera back so the body has air
    Default orbit distance was filling the frame. Start farther out.
2026-09-04 fix: cut the hero caption and orbit hint
    The model does not need a label. Grab cursor is enough.
2026-09-04 fix: plot the hero as a translucent CAD drawing
    Drop the studio PBR pass. Ghost fill plus feature edges so the Meshy
    body reads as an early construction view — white lines on dark paper,
    ink on light.
2026-09-10 Add 3090→T4000 translation table and fractal1 live-stack harness.
    CUDA cores are the wrong axis: filters ×0.13, SAM2/LLM ×0.30, no FP8.
    Next cloud SKU is RunPod Blackwell (PRO 4000 quant / PRO 6000 envelope).
    Harness runs look-dev filters, SAM2-tiny, CLIP region embeds, klein 4B snap.
2026-09-10 Add project skill 3090-loadout for fractal1 VRAM/RAM/swap.
    Script ssh's the box and splits zram (compressed RAM) from the disk
    swapfile. Catalog is SAM2-tiny, CLIP, klein 4B — none resident at idle.
2026-09-10 Add /bay EVF: dark brick dashboard, Tailscale feed, last plate.
    Activate-all on aicam-bay. Live JSON on 100.103.147.70:8745 only.
    Pages ships last-plate.json. Space Age lock-in, Tactic Extra Extended
    Black HUD digits. Tungsten/tally/waveform, not neon.
2026-09-10 advise add-stage-bay: accept, ten pins to tasks.
    Reader agt-fable-5-1-arch-review. Architecture (live on tailnet, plate on
    Pages, Tailscale-only bind, DEV gate, dark lock) holds. Pinned: derate
    ownership, BRICK DARK state, residency granularity, power cap, plate
    refresh, fold target, fonts.
2026-09-10 Fold add-bay-feed into living stage-bay spec.
    Create openspec/specs/stage-bay/ with the Tailscale-only loadout feed
    SHALLs and archive the change as 2026-09-10-add-bay-feed.
2026-09-10 Fold add-bay-glass into living stage-bay spec.
    Append the EVF glass SHALLs after the Tailscale feed requirement and
    archive the change as 2026-09-10-add-bay-glass.
2026-09-10 act add-stage-bay: land Fable advise pins on the bay EVF.
    Derates live in 3090-SIM + t4000.ts. Three slate states. AI-on-tube
    is process-level. power.limit from nvidia-smi. MagicDNS + tailscale ip.
    Live is vite-dev only. Font note beside static/fonts.
2026-09-10 Fold add-stage-bay into living stage-bay spec.
    Append the bay section, dark-lock, live-vs-plate, swap split, stack vs
    resident, and HUD type SHALLs after the feed and glass requirements.
    Archive the change as 2026-09-10-add-stage-bay.
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2026-09-10 advise: add-camera-interconnect re-advise send-back (fable-5-1-arch-review)
    Record-first SHALL lists remux as droppable while both plant diagrams
    route satellite masters through Thor remux to the NAS. Delta must name
    the sat storage path and align the drop set. One clause; architecture
    is otherwise accepted.
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2026-09-10 advise: add-camera-interconnect re2 accept (fable-5-1-arch-review)
    Thor-in-the-loop amend answers the one-clause send-back in full.
    Docs-only follow-up task added for INTERCONNECT/STREAM-BUDGET wording.
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2026-09-10 Point agents at daBOM for crib work.
    BOM, ingest, and quotes live in the sister server. Load the dabom
    skill; do not SQL the notebook.
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2026-09-10 steer: 3090 swap-emulator; resident 30fps on T4000 or PRO 6000
    Same software, two realtime hosts. 3090 sequential-swaps SMALL slots.
    SMALL pack on T4000, LARGE on rented PRO 6000. Change still PENDING.
2026-09-10 advise: add-cartridge-model re-advise send-back (power axis, swap formula)
2026-09-10 change: add-cartridge-model watts not a pack axis; swap is always-on plus max slottable
2026-09-10 advise: add-cartridge-model re-advise 2 accept
    Both re-advise sentences (watts not a pack axis; swap = sum(always-on)+max(slottable))
    are in the spec and the checker. Acceptance exits 0. Fold and packer notes on tasks.md.
2026-09-10 advise: add-parakeet-api send-back
    Blind take then compare. Shape holds (Bun Hono :8750 Tailscale-only, daBOM
    well-known trio, CPU INT8 sidecar). Send-back: design contradicts spec on
    resample, health promised in journey but not in spec, sidecar listener
    undecided across DAG, thread ceiling design-only, servers base missing.
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2026-09-11 fix(bay): vaporwave fills the hero; digits sit on dark slates
    Grid and sun are the hero field. VRAM/DRAW plates are near-black so
    cream HUD type stays above 4.5:1. Waveform rides the bottom of the sky.
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2026-09-11 feat(bay): two original slow themes overlay; speed jumps swap the lead
    Hall (pad) and sail (pentatonic arp) both play when the brick is quiet.
    A util/draw jump raises the chance of swapping which melody leads.
    Not the Tron Legacy scores.
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2026-09-14 feat(deploy): serve the notebook from fractal1 with a live bay
    nginx on the Tailscale IP (:80) and loopback (:8080) serves a static
    build of main from /srv/aicam/site and proxies /bay-api to the bay feed
    on :8745. aicam-site-build.timer checks origin/main every 5 min, runs
    bun install + build (BASE_PATH='', VITE_BAY_LIVE=1), and swaps the site
    symlink atomically.
    Also unbreaks main's build, red on Pages since 2026-09-11:
    - archived datasheet-pack spec linked one ../ short (prerender 404)
    - package-lock.json was out of sync (no chiptune3); CI now uses bun.lock
    Claude-Session: https://claude.ai/code/session_01Qx6gVukAbvLqVMit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
2026-09-14 fix(deploy): drop duplicate glb/stl types, size the types hash
    Claude-Session: https://claude.ai/code/session_01Qx6gVukAbvLqVMit33aweQ
2026-09-14 feat(deploy): public read-only HTTPS at aicam.vm.worldtree.network
    The tracker's default themes and loaded cartridges need a secure context
    (AudioWorklet); http://fractal1 is not one. HTTPS now comes from the
    Mjolnir public gateway: route aicam → proxy VM 612b91a6 :3000 → reverse
    SSH over Iroh (aicam-tunnel.service, autossh + mj proxy) → a new nginx
    server on 127.0.0.1:8081.
    That server is read-only: GET/HEAD only, /bay-api/loadout.json is the
    only feed path, so mag pull/eject stay tailnet-only. The VM key may only
    reverse-forward 0.0.0.0:3000.
    Bay code: randomUUID fallback for mod ids; a clear "Cartridges need
    HTTPS" error where AudioWorklet is missing.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
2026-10-29 Drop the Bay plate from the hardware notebook.
    The live bay is fractal1-web. The Pages route was a frozen 2026-09-10 instrument, so the nav no longer links it.
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2026-10-29 Replace the decision ledger with the current intent of the camera.
    The public page was every closed call. Visitors get what we are building now; the full list stays in the repo.
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
